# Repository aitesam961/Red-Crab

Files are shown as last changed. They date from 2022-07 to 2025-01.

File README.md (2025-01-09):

# Red-Crab: An Open Source, Modular PID controller.
RED-CRAB is an Open Source PID Controller designed for easy and flexible prototyping with PID controllers.
Offering vast selection of control parameters, this Project could be implemented in applications from hobbyist projects to home devices to industrial equipment where closed loop systems are required.

The idea of this project is to use a modular approach where different ad-ons could be used with the Basic PID controller board for controlling applications. Add-on Boards will be designed next added to the repository.
(OSHW Community can contribute in designing add-ons).

## Preview
<p align="center">
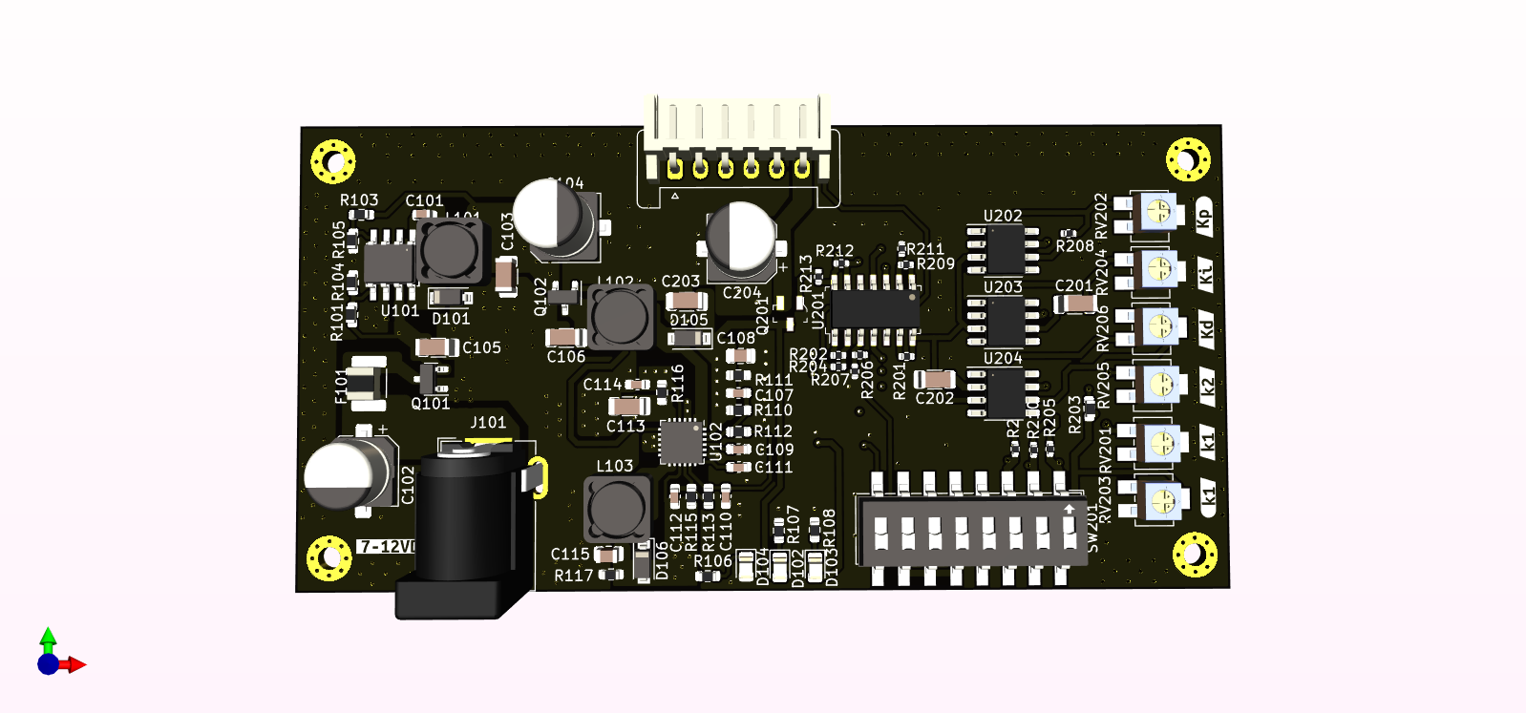
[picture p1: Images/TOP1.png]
  
</p>
<p align="right">
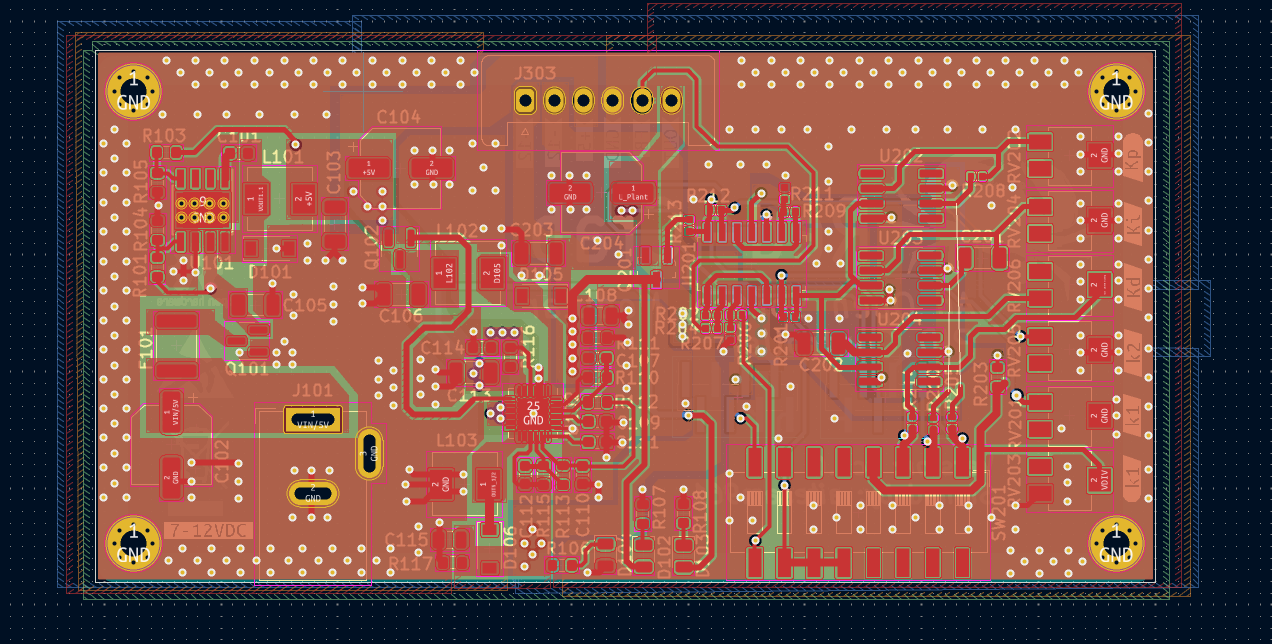
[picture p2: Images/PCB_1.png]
  
</p>
<p align="left">
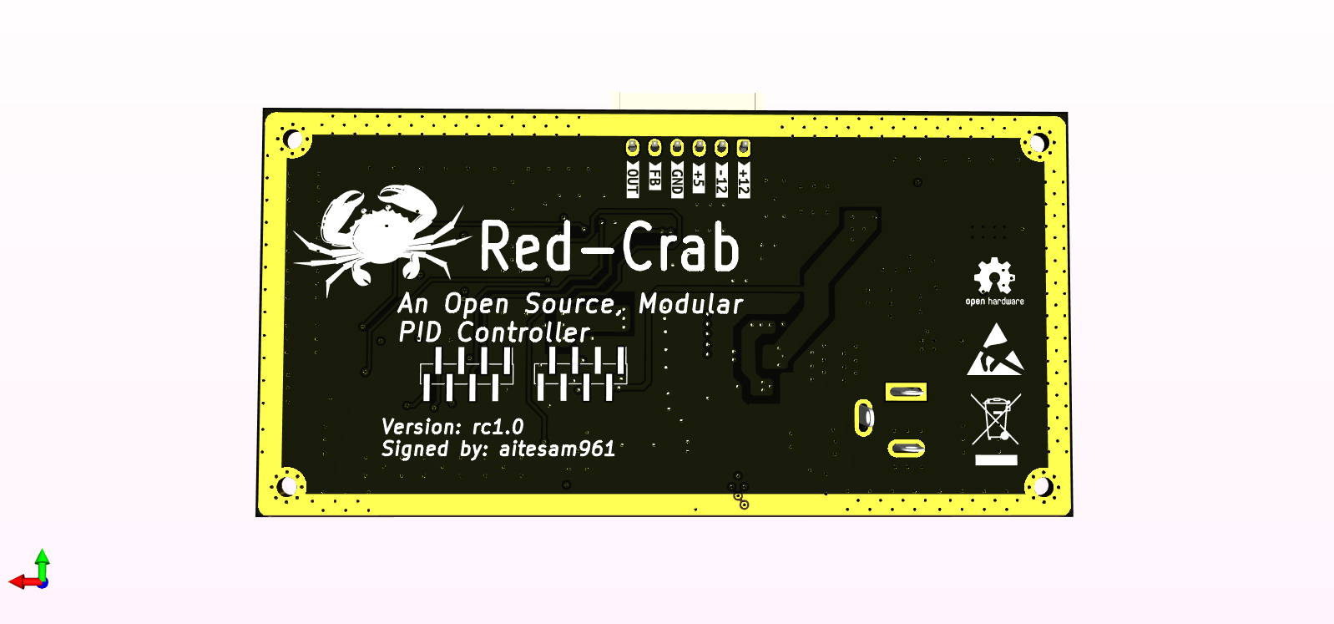
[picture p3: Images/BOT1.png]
  
</p>

## Table of contents
* [Red-Crab Overview](https://github.com/aitesam961/Red-Crab/blob/main/README.md#red-crab-overview)
* [How to Use:](https://github.com/aitesam961/Red-Crab/blob/main/README.md#how-to-use)
* [Electrical Specifications](https://github.com/aitesam961/Red-Crab/blob/main/README.md#electrical-specifications)
* [Build Your Own?](https://github.com/aitesam961/Red-Crab/blob/main/README.md#build-your-own)
* [Future Plans](https://github.com/aitesam961/Red-Crab/blob/main/README.md#future-plans)
* [Ordering Info](https://github.com/aitesam961/Red-Crab/blob/main/README.md#ordering-info)
* [Frequently Asked Questions(FAQs)](https://github.com/aitesam961/Red-Crab/blob/main/README.md#frequently-asked-questionsfaqs)
* [General Component Info](https://github.com/aitesam961/Red-Crab/blob/main/README.md#general-component-info)
* [Acknowledgements](https://github.com/aitesam961/Red-Crab/blob/main/README.md#acknowledgements)
* [License](https://github.com/aitesam961/Red-Crab/blob/main/README.md#license)

# Red-Crab Overview
### Features:
* Selectable P,PI,PID configurations.
* Adjustable GAINs using 50kOHM Potentiometers.
* DIP Switches for Controller Configuration
* Wide DC Voltage Input Range 
* 4-Layer Board with special Care to EMC/EMI for use in commercial applications.
* Open Source under GPL 3.0. (See License)
* Integrated Output Current Aplification for Larger Loads
* Ability to power External Peripherals

## How to Use:
## Electrical Specifications:

## Build Your Own?
## Future Plans
In future, this project seeks improvements and Development in following areas:
* Digital to Analog Converter Module (Ad-On Board)
* Temeprature Sensing & Amplification (Ad-On Board)
* Frequency to Voltage Converter (Ad-On Board)
* Integration with ARDUINO for Data Logging (Ad-On Board)
* Servo Actuation Control (Ad-On Board)
* Disturbance Integration Using Arduino (Ad-On Board)
## Ordering Info
You Can manufacture the PCBs from PCBWay.
[Check Out PCBWay](https://www.pcbway.com/setinvite.aspx?inviteid=440401)

Note: I am not affiliated with PCBWay. However, I just like their service and build quality.

## Frequently Asked Questions(FAQs)
## General Component Info

## Roadmap

* [x] Concept Proof
* [x] Research & Information
* [x] Finalizing The Idea
* [x] Schematics
* [x] PCB Design
* [ ] Validation & Testing
* [x] Documentation
* [ ] Future Improvements

### Contributions

Contributions are what make the open source community such an amazing place to learn, inspire, and create. Any contributions you make are **greatly appreciated**.

If you have a suggestion that would make this better, please fork the repo and create a pull request. You can also simply open an issue with the tag "enhancement".
Don't forget to give the project a star! Thanks again!

1. Fork the Project
2. Create your Feature Branch (`git checkout -b feature/AmazingFeature`)
3. Commit your Changes (`git commit -m 'Add some AmazingFeature'`)
4. Push to the Branch (`git push origin feature/AmazingFeature`)
5. Open a Pull Request

## Acknowledgements
This project is created to serve the Open Hardware Community in terms of Analog Controller Design using discrete components. Unfortunately, there isn't much of open source projects in terms of Flexible and Modular PID controller Design area.
Thye crater hopes it helps someone

## File Tree
```
.
├── Documents
│   ├── ibom.html
│   └── PID_Controller_Design.pdf
├── Images
│   ├── BOT1.png
│   ├── BOT1_RT.png
│   ├── PCB_1.png
│   ├── SID1_RT.png
│   ├── TOP1.png
│   ├── TOP1_RT.png
│   ├── TOP2_RT.png
│   ├── TOP3_RT.png
│   └── TOP4_RT.png
├── LICENSE.txt
├── Manufacturing Files
│   ├── bom.csv
│   ├── designators.csv
│   ├── gerber.zip
│   ├── netlist.ipc
│   └── positions.csv
├── MCAD Files
│   ├── Red-Crab.step
│   └── Red-Crab.wrl
├── README.md
├── Readme.txt.txt
├── References
│   ├── BananaSchplit-master
│   │   └── BananaSchplit-master
│   │       ├── assembly
│   │       │   ├── BananaSchplit-BOM.csv
│   │       │   └── BananaSchplit-Footprint-Positions.csv
│   │       ├── BananaSchplit-cache.lib
│   │       ├── BananaSchplit.kicad_pcb
│   │       ├── BananaSchplit.kicad_pcb-bak
│   │       ├── BananaSchplit.net
│   │       ├── BananaSchplit.pro
│   │       ├── BananaSchplit-rescue.dcm
│   │       ├── BananaSchplit-rescue.lib
│   │       ├── BananaSchplit.sch
│   │       ├── BananaSchplit.sch-bak
│   │       ├── BananaSchplit.xml
│   │       ├── fp-info-cache
│   │       ├── fp-lib-table
│   │       ├── gerber
│   │       │   ├── BananaSchplit-B_Cu.gbr
│   │       │   ├── BananaSchplit-B_Mask.gbr
│   │       │   ├── BananaSchplit-B_Paste.gbr
│   │       │   ├── BananaSchplit-B_SilkS.gbr
│   │       │   ├── BananaSchplit.drl
│   │       │   ├── BananaSchplit-Edge_Cuts.gbr
│   │       │   ├── BananaSchplit-F_Cu.gbr
│   │       │   ├── BananaSchplit-F_Mask.gbr
│   │       │   ├── BananaSchplit-F_Paste.gbr
│   │       │   ├── BananaSchplit-F_SilkS.gbr
│   │       │   └── BananaSchplit-Gerber.zip
│   │       ├── lib
│   │       │   ├── BananSchplitSilk.pretty
│   │       │   │   ├── BananaSchplitDrawn.png
│   │       │   │   ├── BananaSchplit.png
│   │       │   │   ├── BananaSchplitSilkLogoDrawn.kicad_mod
│   │       │   │   └── BananaSchplitSilkLogo.kicad_mod
│   │       │   ├── TPS65131RGET.lib
│   │       │   ├── TPS65131RGET.mod
│   │       │   └── TPS65131RGET.stp
│   │       ├── LICENSE
│   │       ├── README.md
│   │       └── sym-lib-table
│   ├── Screenshot 2022-07-08 204516.png
│   └── The_Design_of_the_PID_Controller.pdf
└── Source Files
    └── Red_Crab_KiCAD_Source
        ├── fp-info-cache
        ├── Passives.kicad_sch
        ├── PID_Core.kicad_sch
        ├── place_footprints.log
        ├── Power.kicad_sch
        ├── Red-Crab.kicad_pcb
        ├── Red-Crab.kicad_prl
        ├── Red-Crab.kicad_pro
        ├── Red-Crab.kicad_sch
        └── shapes3D
            ├── C_0603_1608Metric.wrl
            ├── C_0805_2012Metric.wrl
            ├── C_1206_3216Metric.wrl
            ├── CP_Elec_6.3x5.3.wrl
            ├── CP_Elec_6.3x7.7.wrl
            ├── DC-jack.wrl
            ├── D_SOD-123.wrl
            ├── Fuse_1210_3225Metric.wrl
            ├── HSOP-8-1EP_3.9x4.9mm_P1.27mm_EP2.41x3.1mm.wrl
            ├── HTSOP-8-1EP_3.9x4.9mm_Pitch1.27mm.wrl
            ├── JST_EH_S6B-EH_1x06_P2.50mm_Horizontal.wrl
            ├── L_Bourns_SRR1260.wrl
            ├── LED_0805_2012Metric.wrl
            ├── POT_SMD.wrl
            ├── QFN-24-1EP_4x4mm_P0.5mm_EP2.6x2.6mm.wrl
            ├── R_0402_1005Metric.wrl
            ├── R_0603_1608Metric.wrl
            ├── SOIC-14_3.9x8.7mm_P1.27mm.wrl
            ├── SOT-23.wrl
            └── SW_DIP_SPSTx08_Slide_6.7x21.88mm_W8.61mm_P2.54mm_LowProfile.wrl

14 directories, 87 files
```
## License
This Project is published under General Public License V3.0 See `LICENSE.txt` for more information.
> https://www.gnu.org/licenses/quick-guide-gplv3.html

<p align="right">(<a href="#top">back to top</a>)</p>

* [Jump To Start](https://github.com/maitesam/OpenADSP/blob/main/README.md#Description)

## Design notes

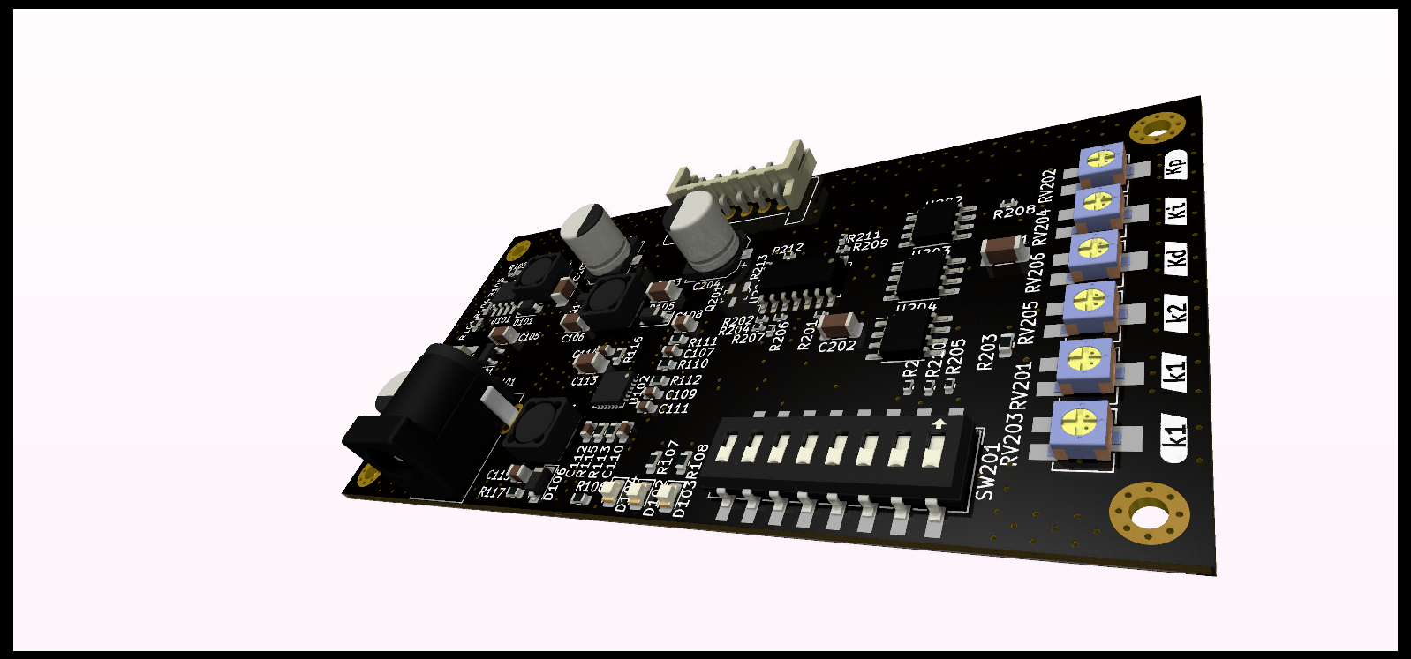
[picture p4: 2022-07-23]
Images/SID1_RT.png

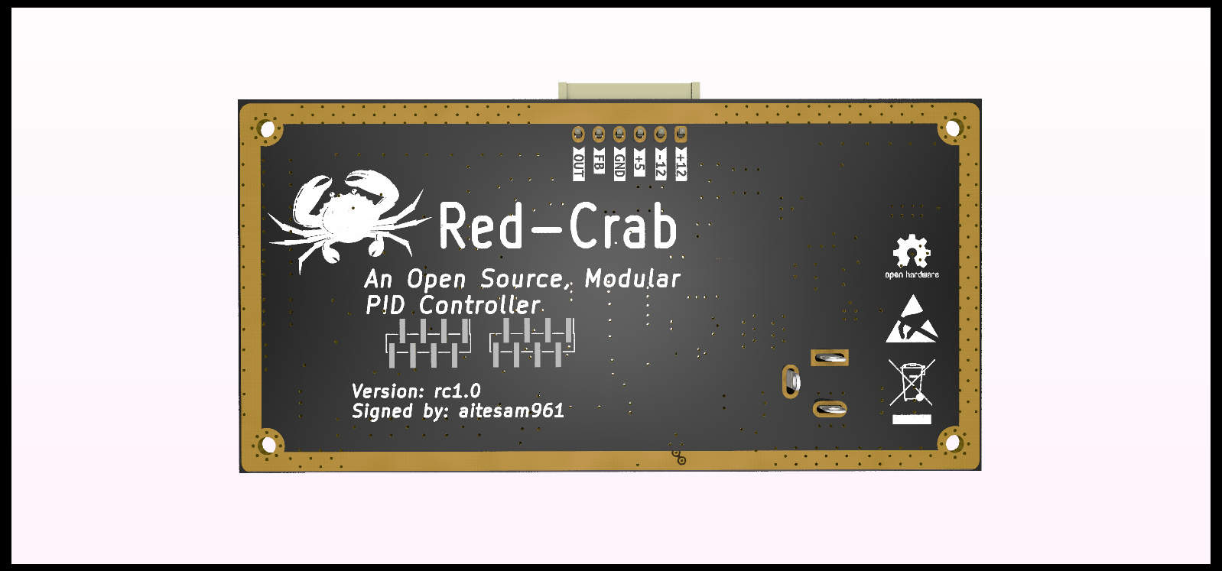
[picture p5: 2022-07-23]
Images/BOT1_RT.png

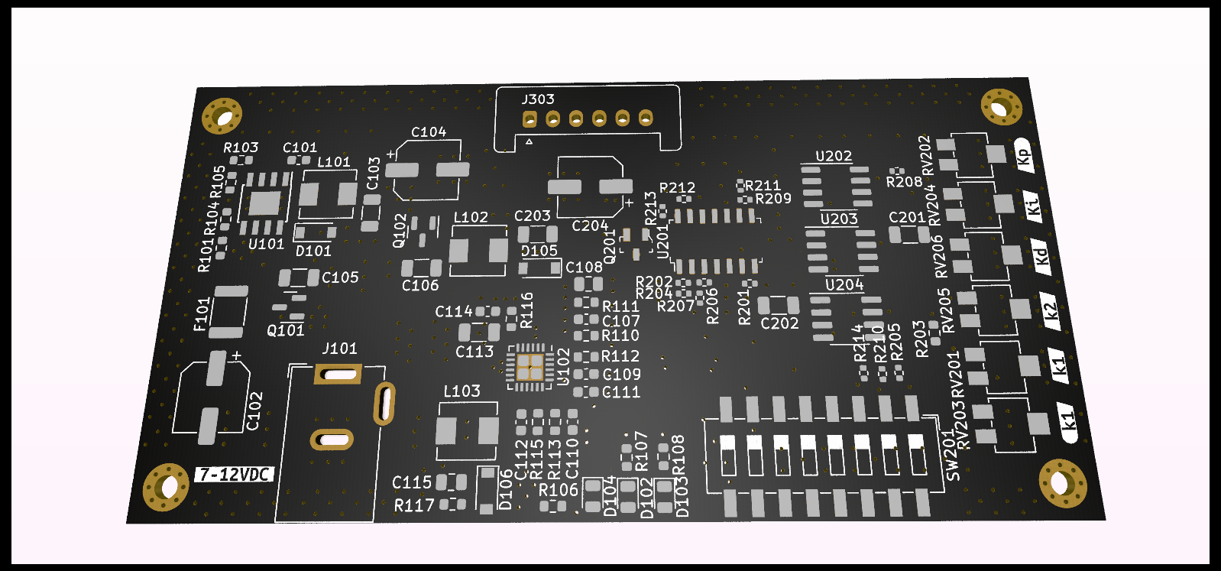
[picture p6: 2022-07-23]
Images/TOP4_RT.png

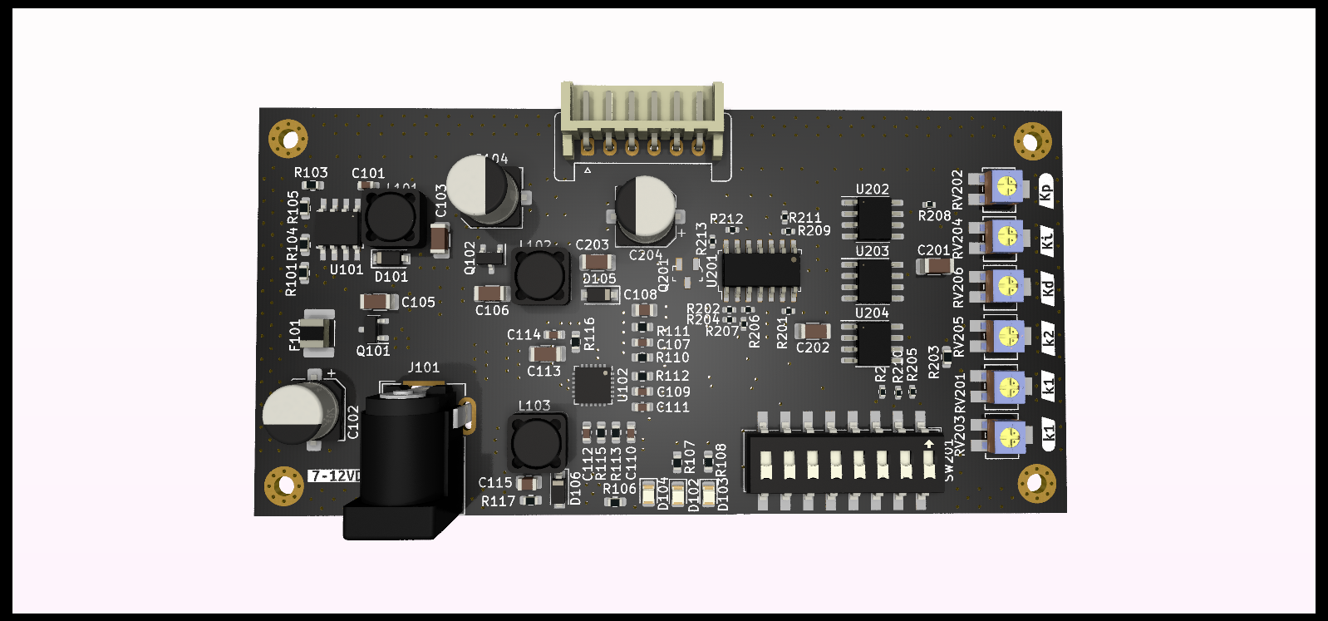
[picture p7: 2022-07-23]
Images/TOP3_RT.png

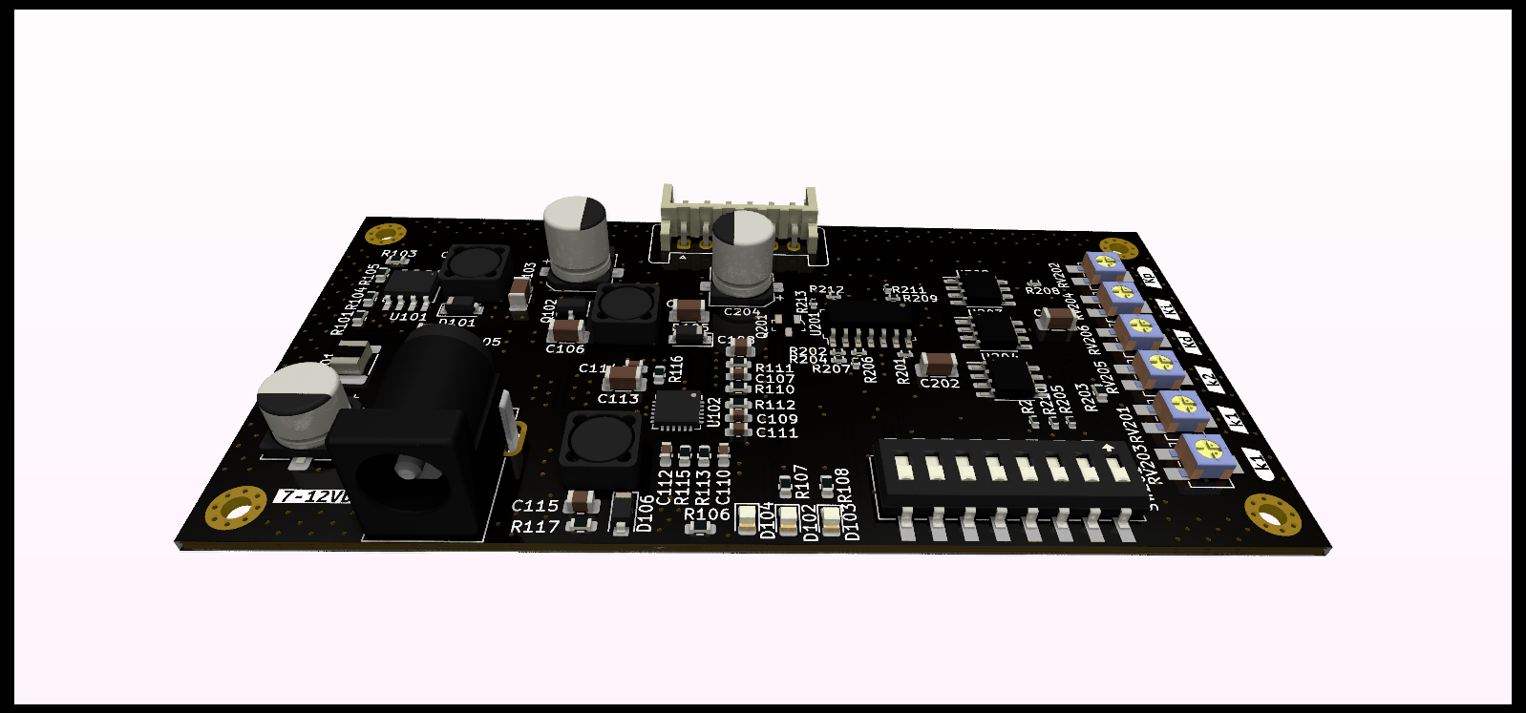
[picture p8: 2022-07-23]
Images/TOP1_RT.png

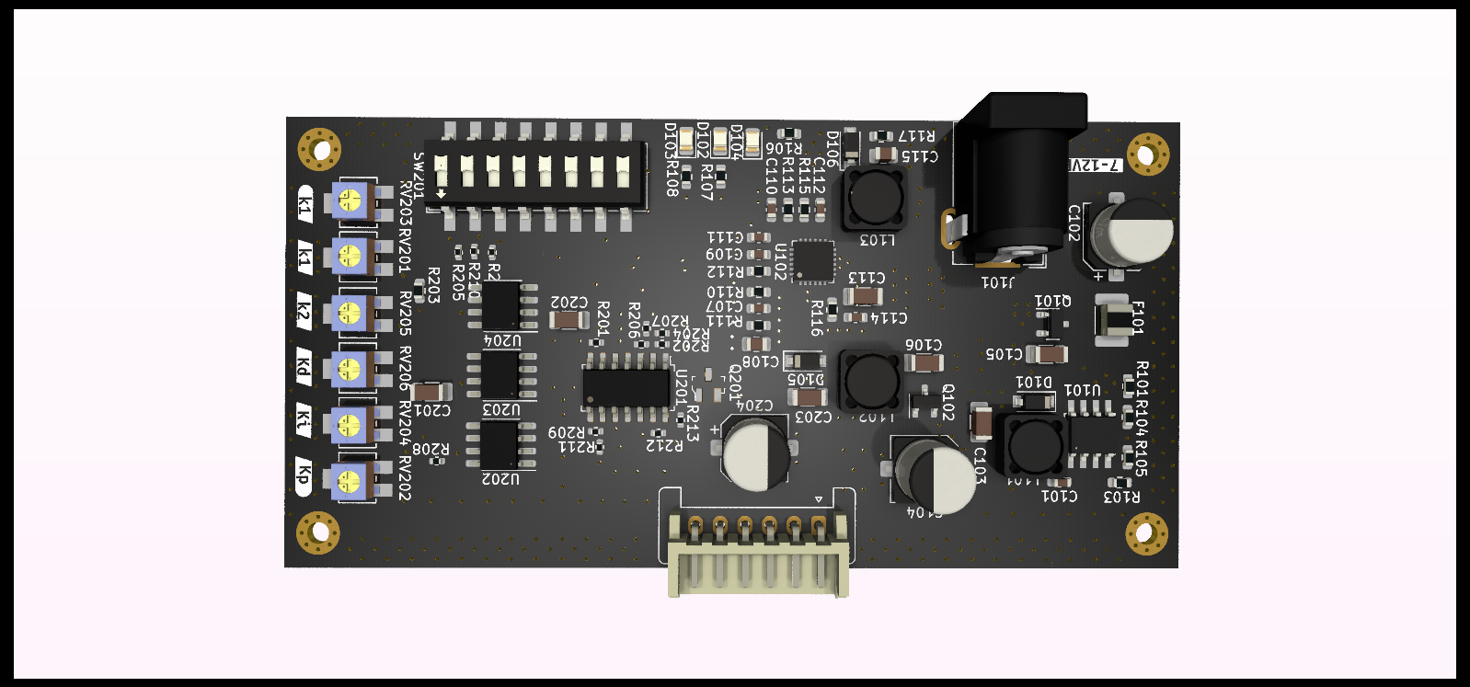
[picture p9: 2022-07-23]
Images/TOP2_RT.png

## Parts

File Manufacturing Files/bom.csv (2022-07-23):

Designator | Footprint | Quantity | Value | LCSC Part #
J303 | Stocko_MKS_1656-6-0-606_1x6_P2.50mm_Vertical | 1 | Screw_Terminal_01x06
RV204 | Potentiometer_Bourns_3214X_Vertical | 1 | 100k
RV203 | Potentiometer_Bourns_3214X_Vertical | 1 | 50k
U203 | SOP-8_3.76x4.96mm_P1.27mm | 1 | LM741
C105 | C_1206_3216Metric | 1 | 10u | C13585
R117 | R_0603_1608Metric | 1 | 12k | C22790
U204 | SOP-8_3.76x4.96mm_P1.27mm | 1 | LM741
Q101 | SOT-23 | 1 | AO3401A | C15127
C103 | C_1206_3216Metric | 1 | 10u | C13585
C113 | C_1206_3216Metric | 1 | 10u | C13585
R205 | R_0402_1005Metric | 1 | 1k
H302 | MountingHole_2.2mm_M2_Pad_Via | 1 | MountingHole_Pad
RV206 | Potentiometer_Bourns_3214X_Vertical | 1 | 100k
C101 | C_0603_1608Metric | 1 | 10n | C57112
R213 | R_0402_1005Metric | 1 | 100
R106 | R_0603_1608Metric | 1 | 5k1 | C23186
R202 | R_0402_1005Metric | 1 | 1k
D104 | LED_0805_2012Metric | 1 | YELLOW | C2296
R111 | R_0603_1608Metric | 1 | 12k | C22790
C109 | C_0603_1608Metric | 1 | 10n | C57112
R107 | R_0603_1608Metric | 1 | 4k3 | C23159
D105 | D_SOD-123 | 1 | B5819W | C8598
R212 | R_0402_1005Metric | 1 | 1k
U202 | SOP-8_3.76x4.96mm_P1.27mm | 1 | LM741
D101 | D_SOD-123 | 1 | B5819W | C8598
C102 | CP_Elec_6.3x5.3 | 1 | 22uF/25V
RV202 | Potentiometer_Bourns_3214X_Vertical | 1 | 50k
R203 | R_0603_1608Metric | 1 | 10k | C22775
H301 | MountingHole_2.2mm_M2_Pad_Via | 1 | MountingHole_Pad
C204 | CP_Elec_6.3x7.7 | 1 | 220u | C127327
J101 | BarrelJack_GCT_DCJ200-10-A_Horizontal | 1 | Barrel_Jack_Switch
R104 | R_0603_1608Metric | 1 | 100k | C25803
C104 | CP_Elec_6.3x7.7 | 1 | 220u | C127327
R207 | R_0402_1005Metric | 1 | 1k
H304 | MountingHole_2.2mm_M2_Pad_Via | 1 | MountingHole_Pad
Q201 | SOT-23-3 | 1 | FDV301N | FDV301N
Q102 | SOT-23 | 1 | AO3401A | C15127
R204 | R_0402_1005Metric | 1 | 1k
C201 | C_1206_3216Metric | 1 | 1u | C13585
C202 | C_1206_3216Metric | 1 | 1u | C13585
R105 | R_0603_1608Metric | 1 | 3k3 | C22978
R201 | R_0402_1005Metric | 1 | 1k
L101 | L_Sunlord_MWSA0518_5.4x5.2mm | 1 | 47u | C169398
R116 | R_0603_1608Metric | 1 | 100 | C22775
U101 | TI_SO-PowerPAD-8_ThermalVias | 1 | TPS5430DDA | C9864
C106 | C_1206_3216Metric | 1 | 10u | C13585
R113 | R_0603_1608Metric | 1 | 100k | C25803
R210 | R_0402_1005Metric | 1 | 1k
R110 | R_0603_1608Metric | 1 | 1M | C22935
R206 | R_0402_1005Metric | 1 | 1k
R103 | R_0603_1608Metric | 1 | 10k | C25804
C110 | C_0603_1608Metric | 1 | 220n | C21120
L103 | L_Sunlord_MWSA0518_5.4x5.2mm | 1 | 10u | C139506
R115 | R_0603_1608Metric | 1 | 1M | C22935
D103 | LED_0805_2012Metric | 1 | RED | C84256
R112 | R_0603_1608Metric | 1 | 110k | C25805
C107 | C_0603_1608Metric | 1 | 6p8 | C1679
RV201 | Potentiometer_Bourns_3214X_Vertical | 1 | 50k
SW201 | SW_DIP_SPSTx08_Slide_6.7x21.88mm_W8.61mm_P2.54mm_LowProfile | 1 | SW_DIP_x06
C203 | C_1206_3216Metric | 1 | 10u | C13585
L102 | L_Sunlord_MWSA0518_5.4x5.2mm | 1 | 10u | C139506
C115 | C_0805_2012Metric | 1 | 22u | C45783
C114 | C_0603_1608Metric | 1 | 100n | C14663
H303 | MountingHole_2.2mm_M2_Pad_Via | 1 | MountingHole_Pad
C112 | C_0603_1608Metric | 1 | 8p2 | C1685
R101 | R_0603_1608Metric | 1 | 100k | C25803
R208 | R_0402_1005Metric | 1 | 1k
F101 | Fuse_1812_4532Metric | 1 | 500mA | C151168
D102 | LED_0805_2012Metric | 1 | GREEN | C2297
C111 | C_0603_1608Metric | 1 | 4n7 | C53987
D106 | D_SOD-123 | 1 | B5819W | C8598
R214 | R_0402_1005Metric | 1 | 1k
R209 | R_0402_1005Metric | 1 | 6k
C108 | C_0805_2012Metric | 1 | 22u | C45783
R211 | R_0402_1005Metric | 1 | 6k
U102 | QFN-24-1EP_4x4mm_P0.5mm_EP2.6x2.6mm | 1 | TPS65131RGER | C87663
U201 | SOIC-14_W3.9mm | 1 | LM324ADR | LM324ADR
R108 | R_0603_1608Metric | 1 | 1k5 | C22843
RV205 | Potentiometer_Bourns_3214X_Vertical | 1 | 50k
J302 | PinHeader_1x08_P1.27mm_Vertical_SMD_Pin1Left | 1 | OSTTC080162 | OSTTC080162
J301 | PinHeader_1x08_P1.27mm_Vertical_SMD_Pin1Left | 1 | OSTTC080162 | OSTTC080162

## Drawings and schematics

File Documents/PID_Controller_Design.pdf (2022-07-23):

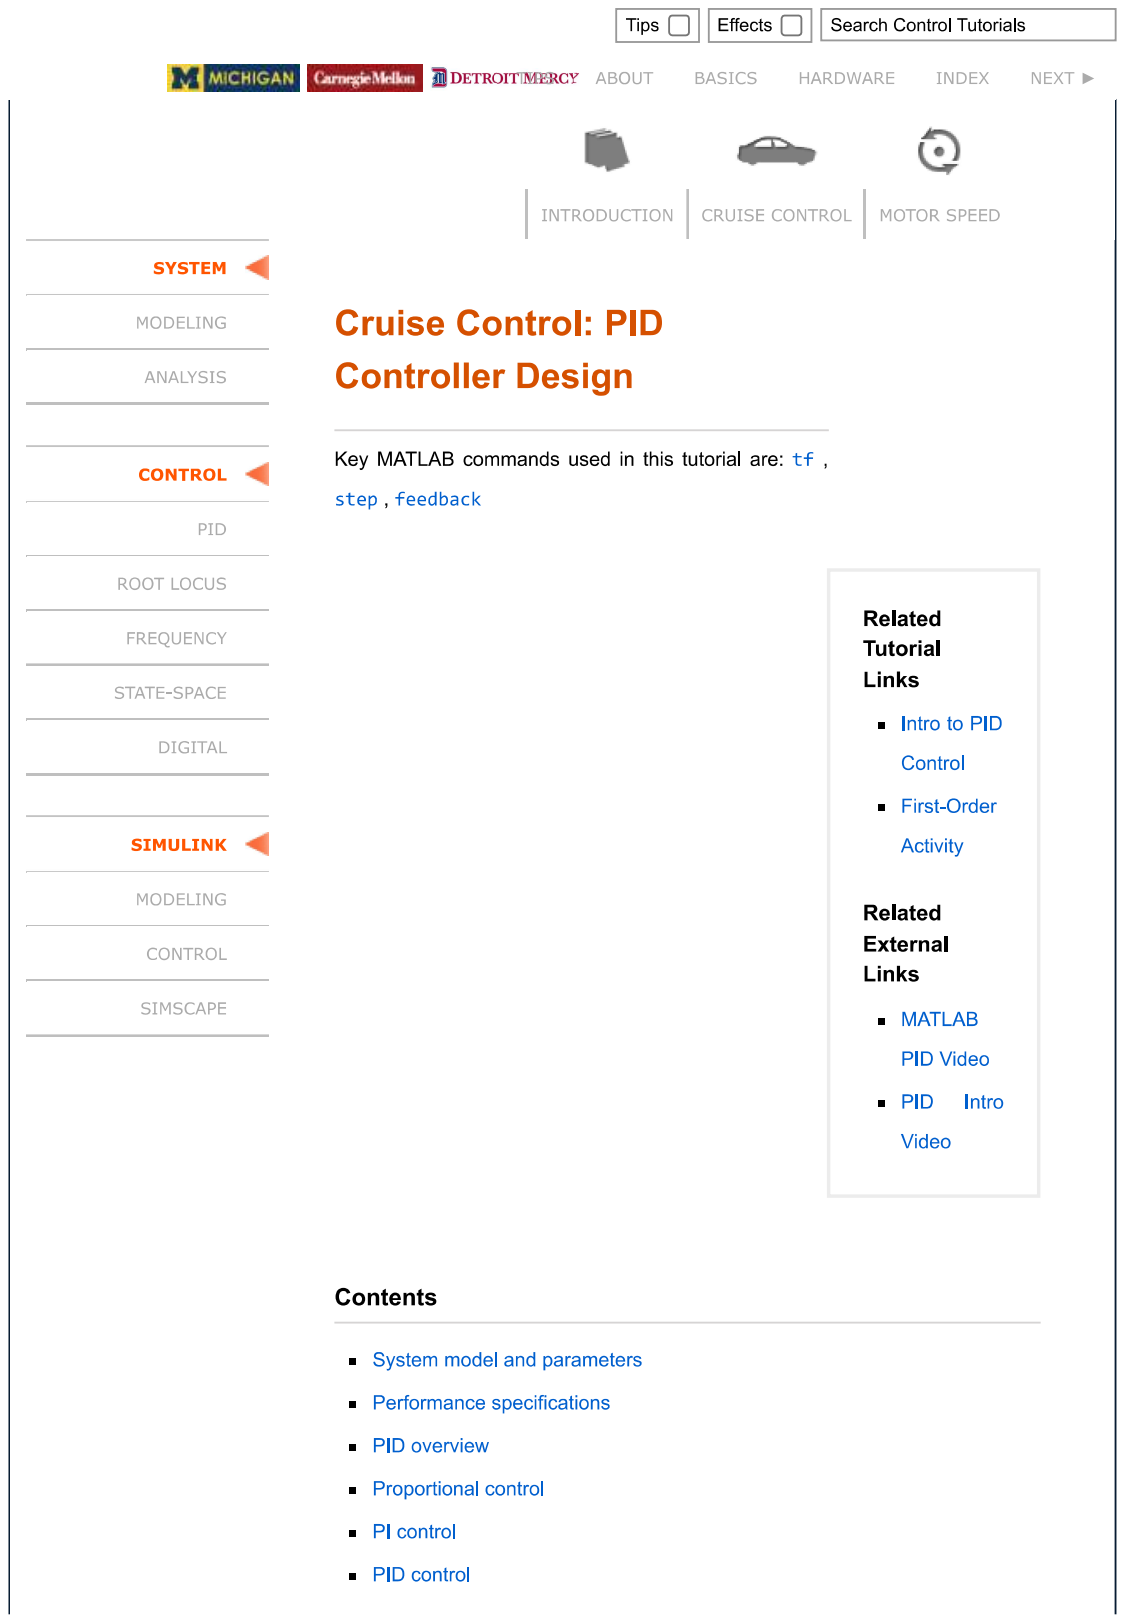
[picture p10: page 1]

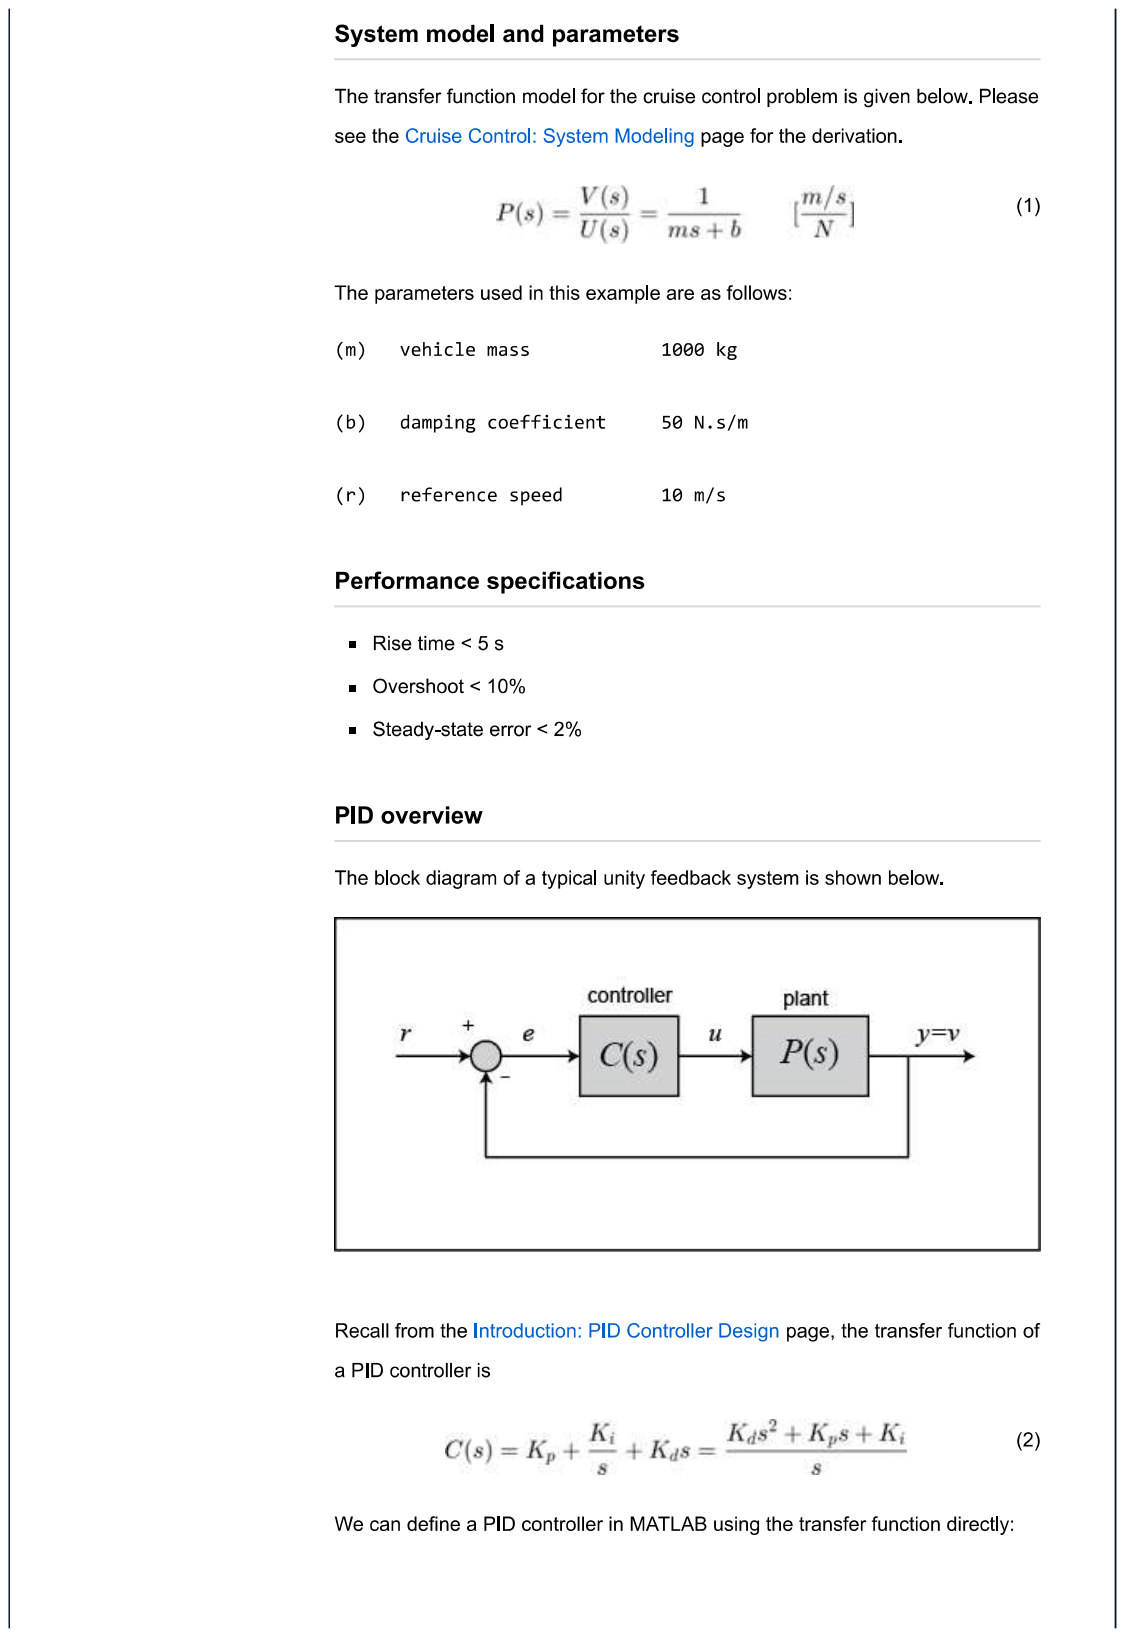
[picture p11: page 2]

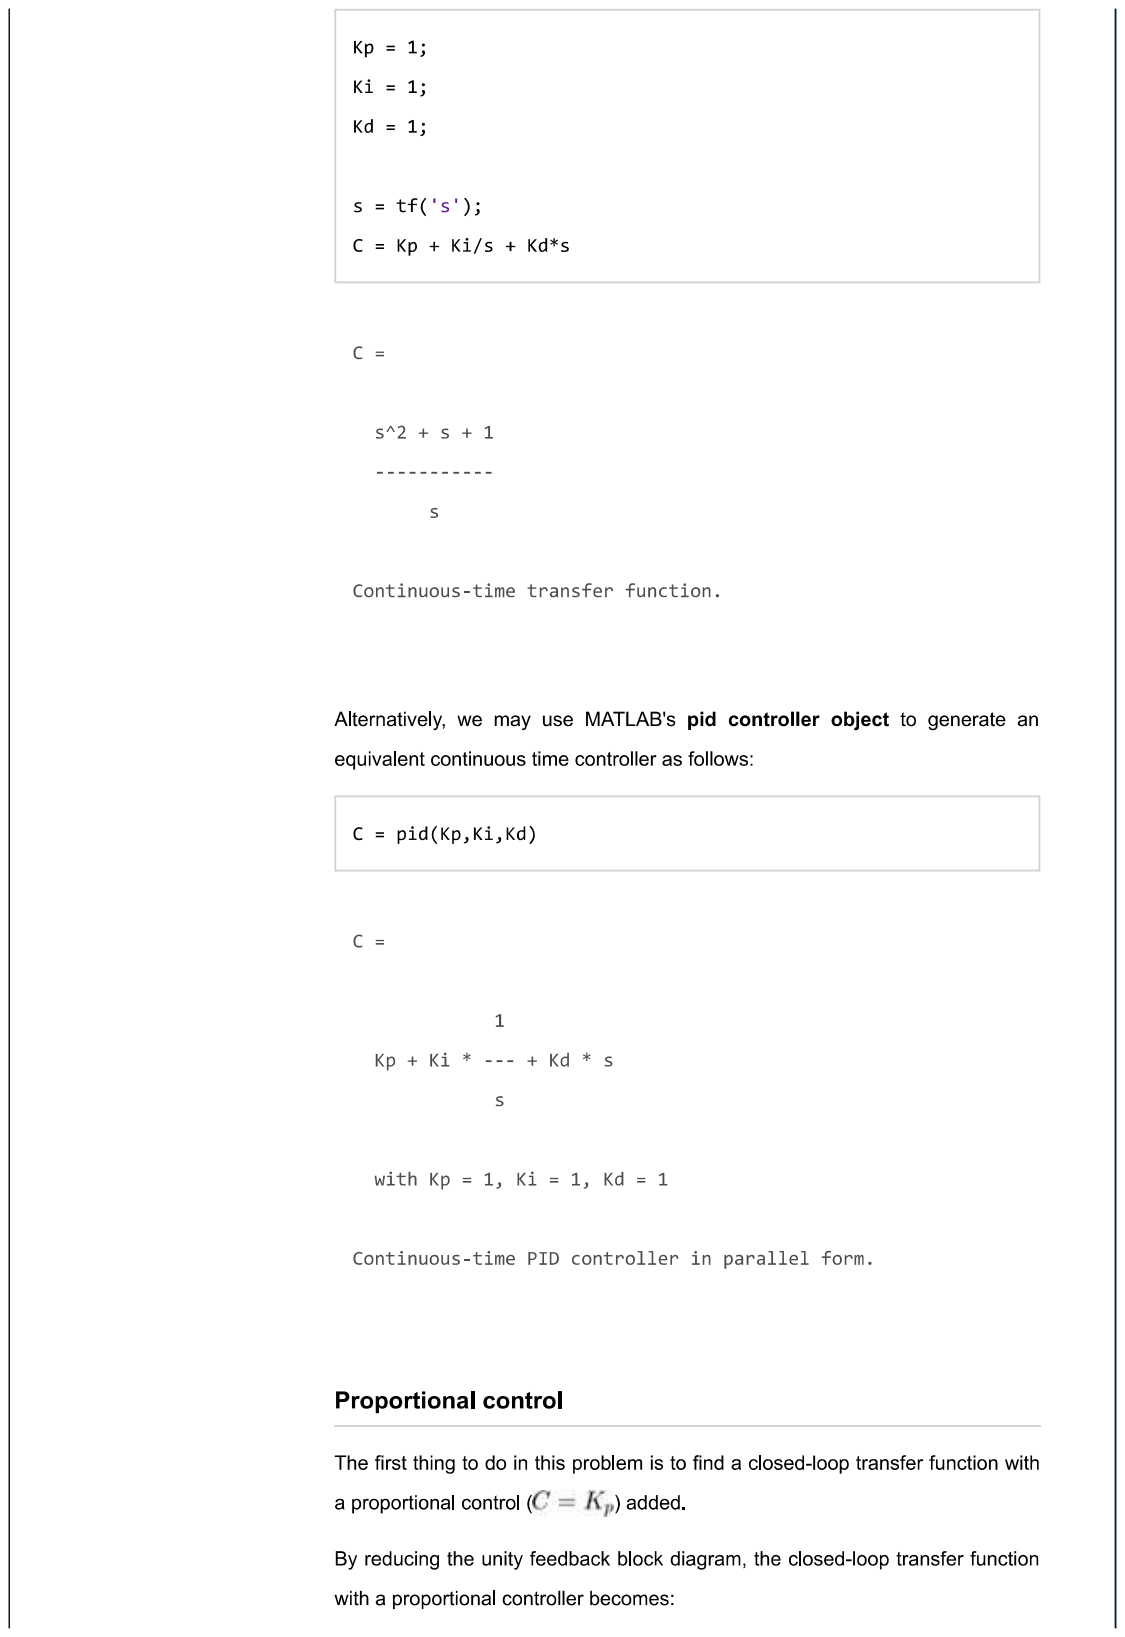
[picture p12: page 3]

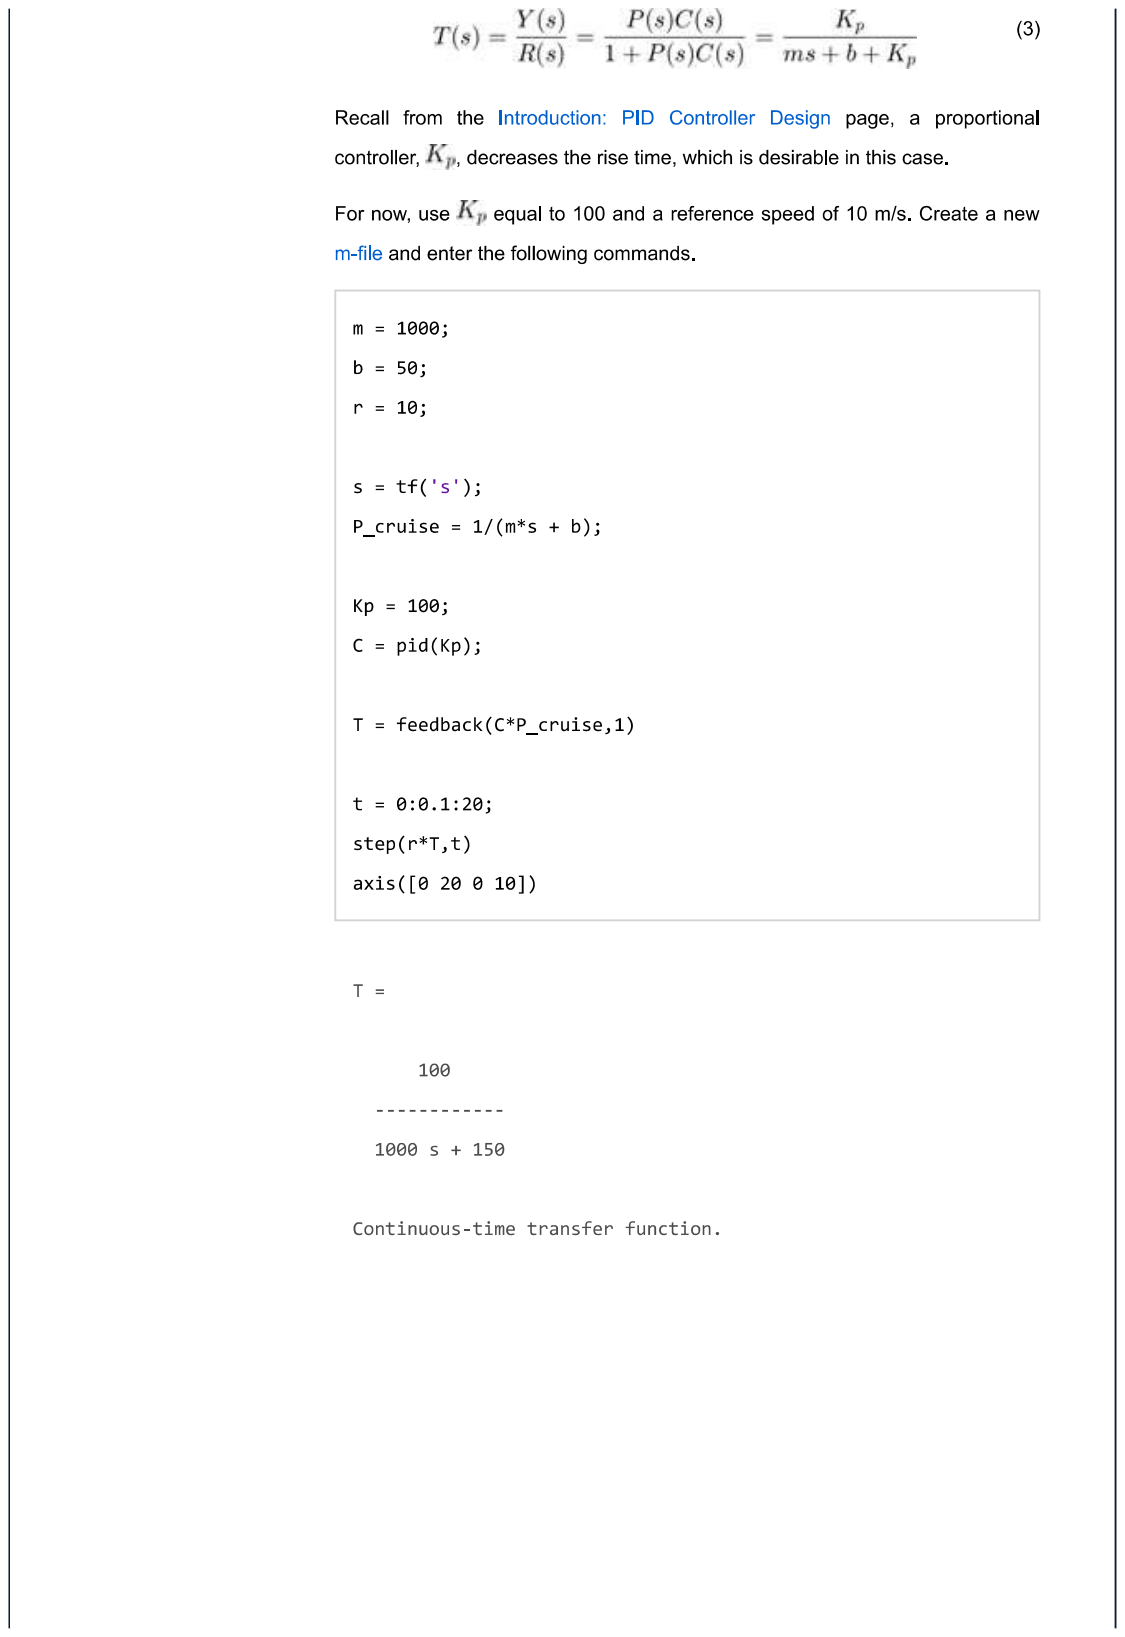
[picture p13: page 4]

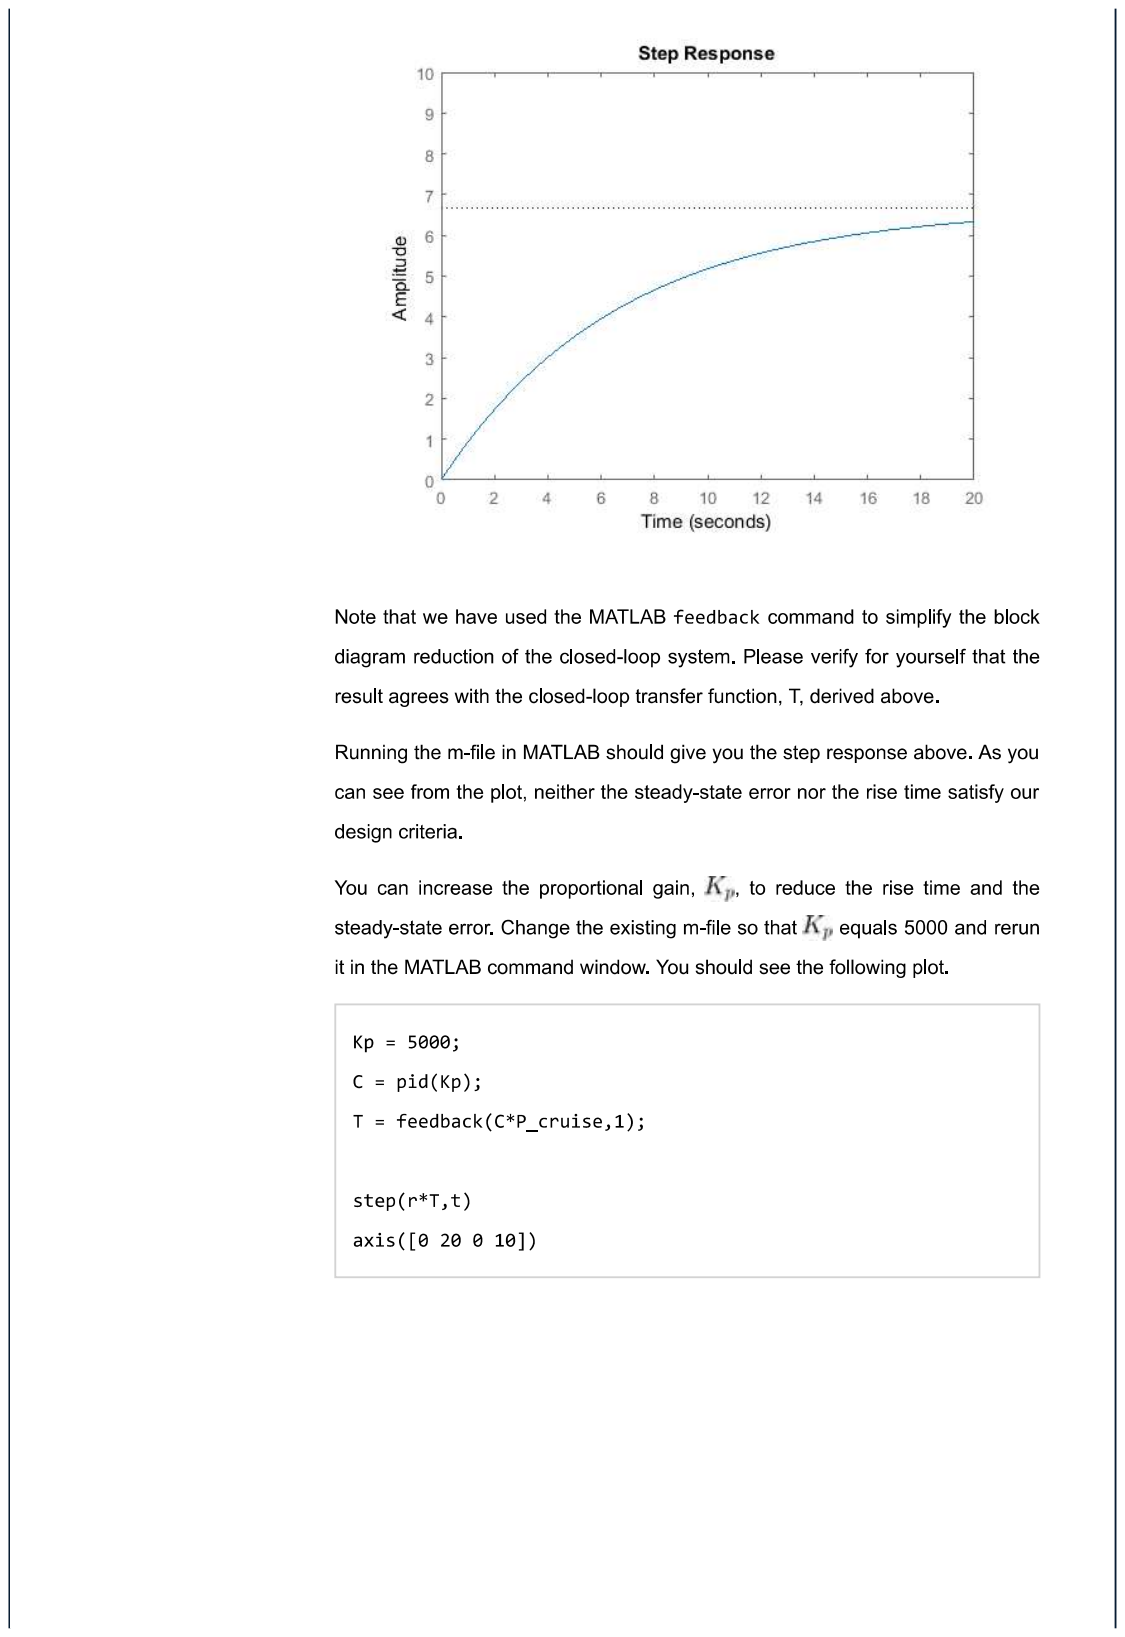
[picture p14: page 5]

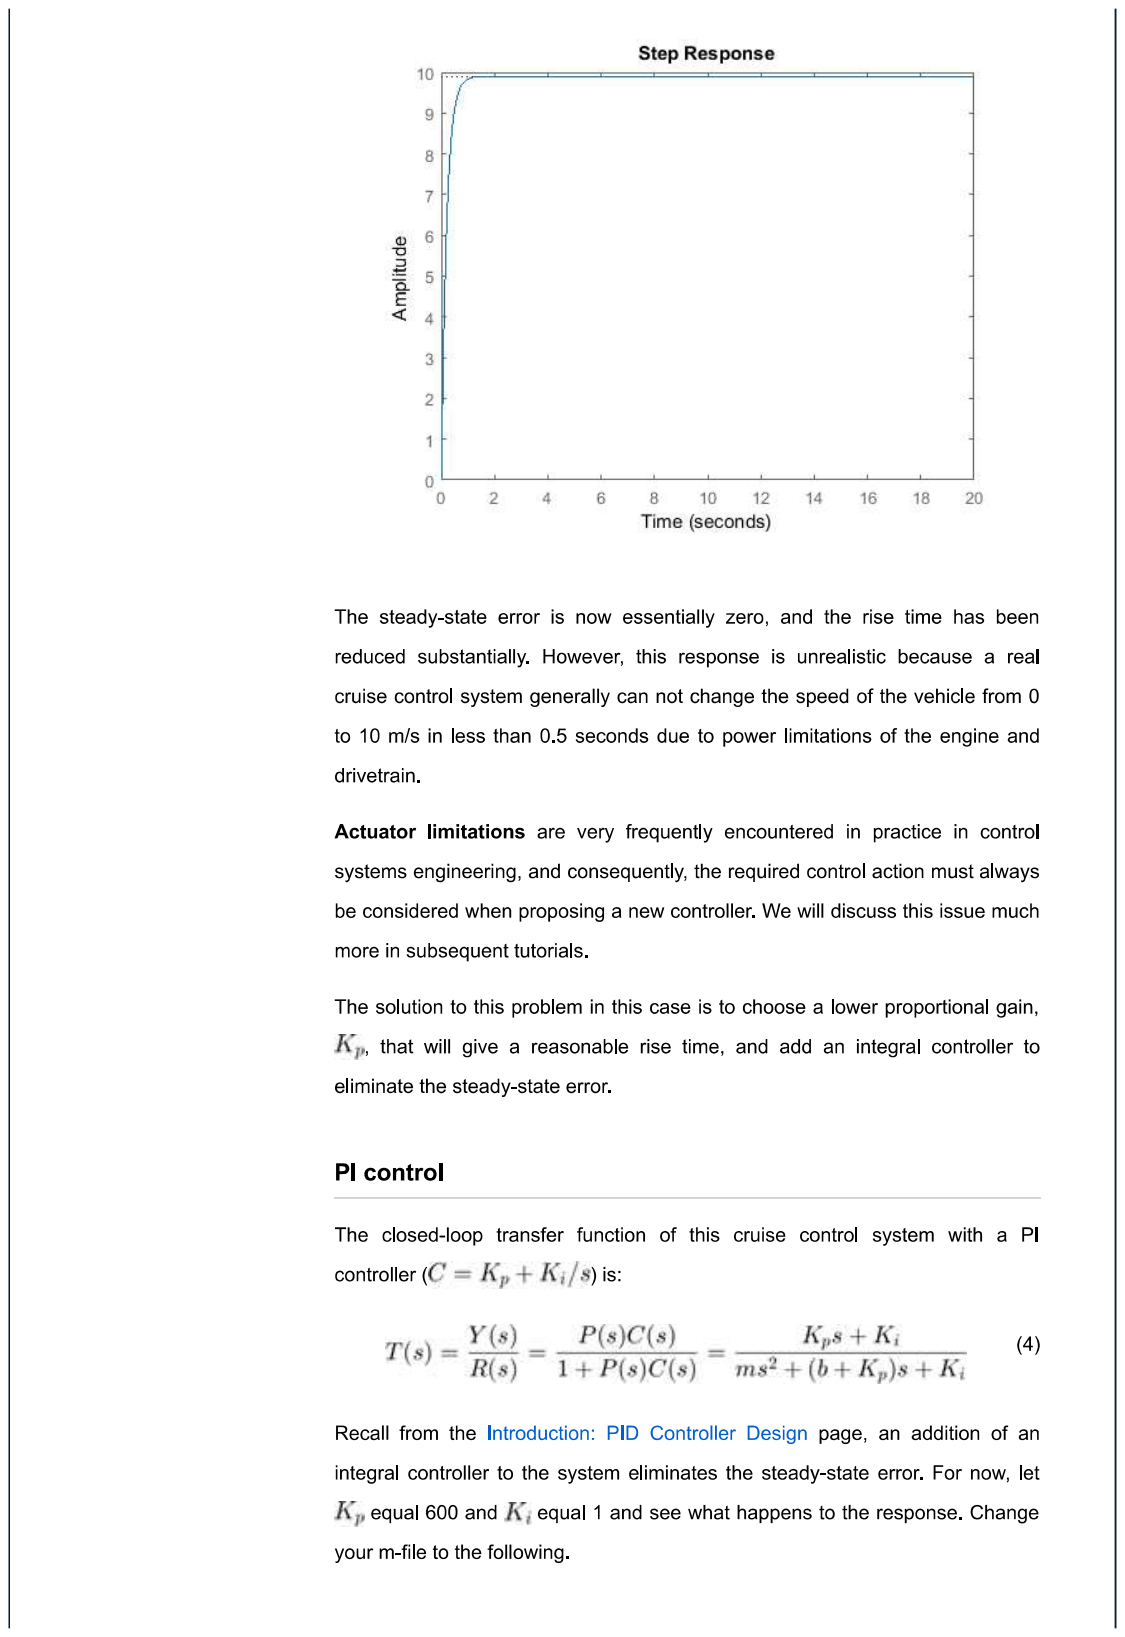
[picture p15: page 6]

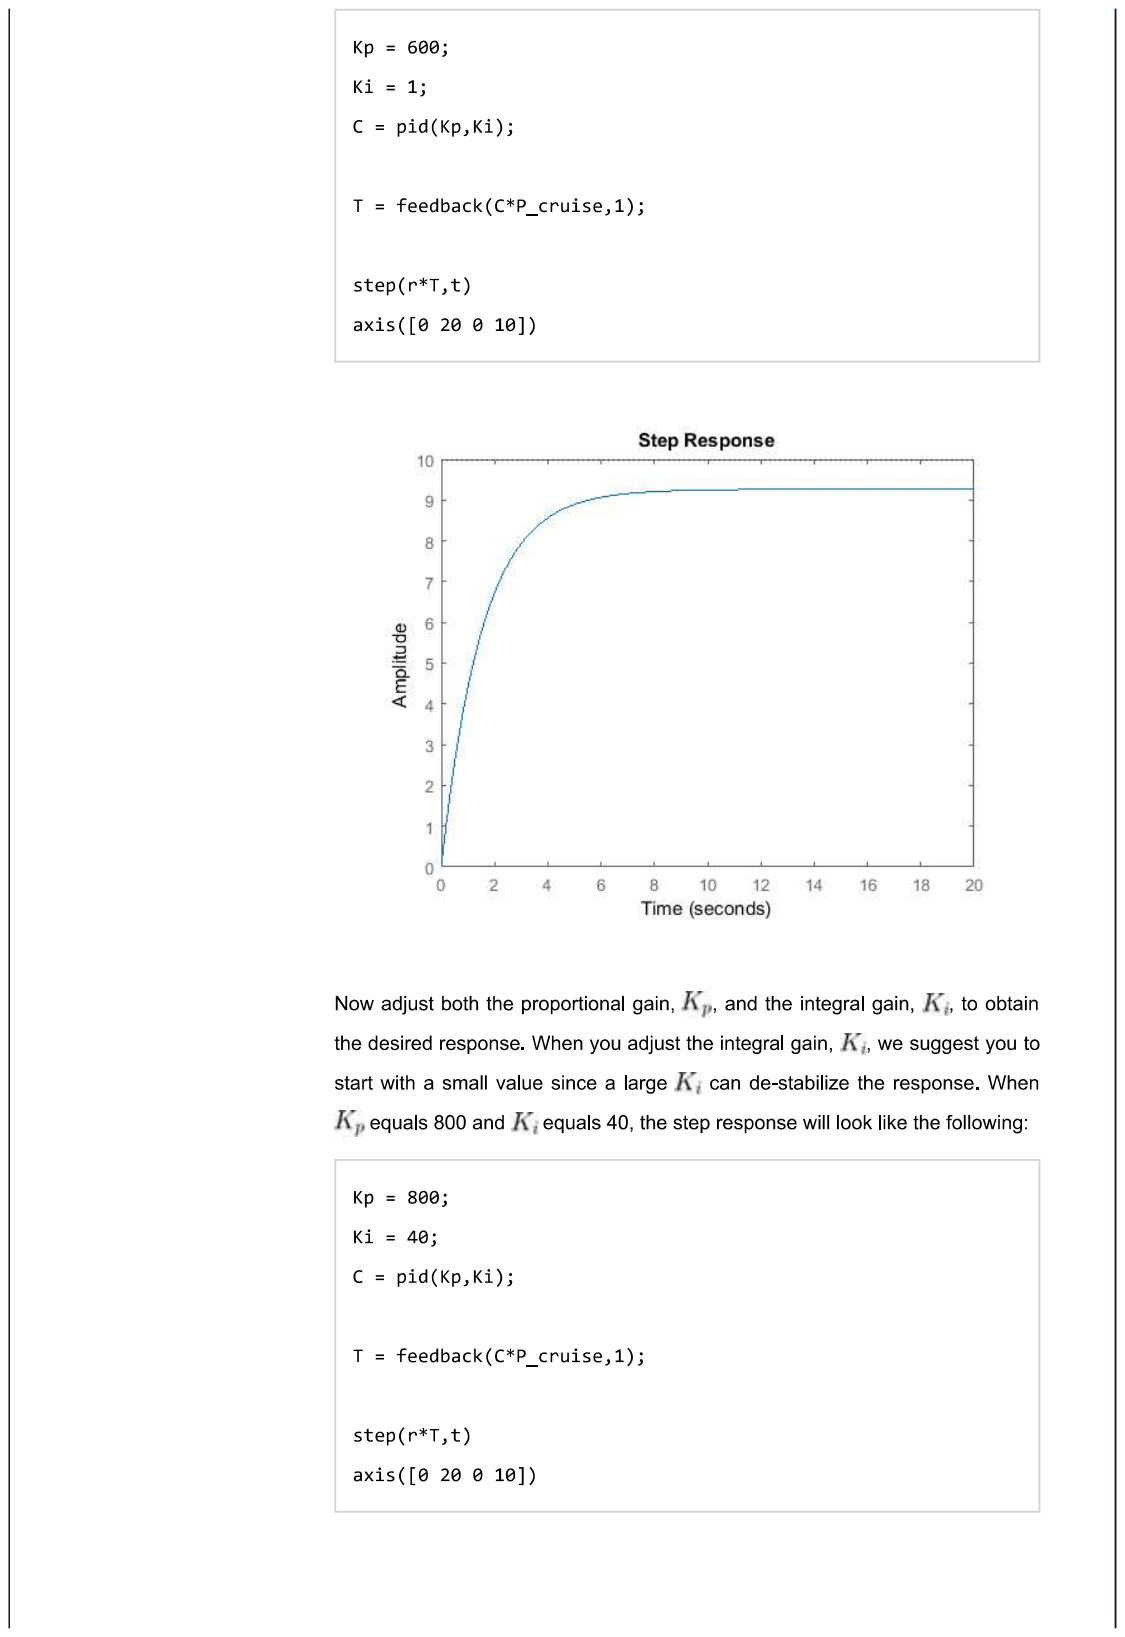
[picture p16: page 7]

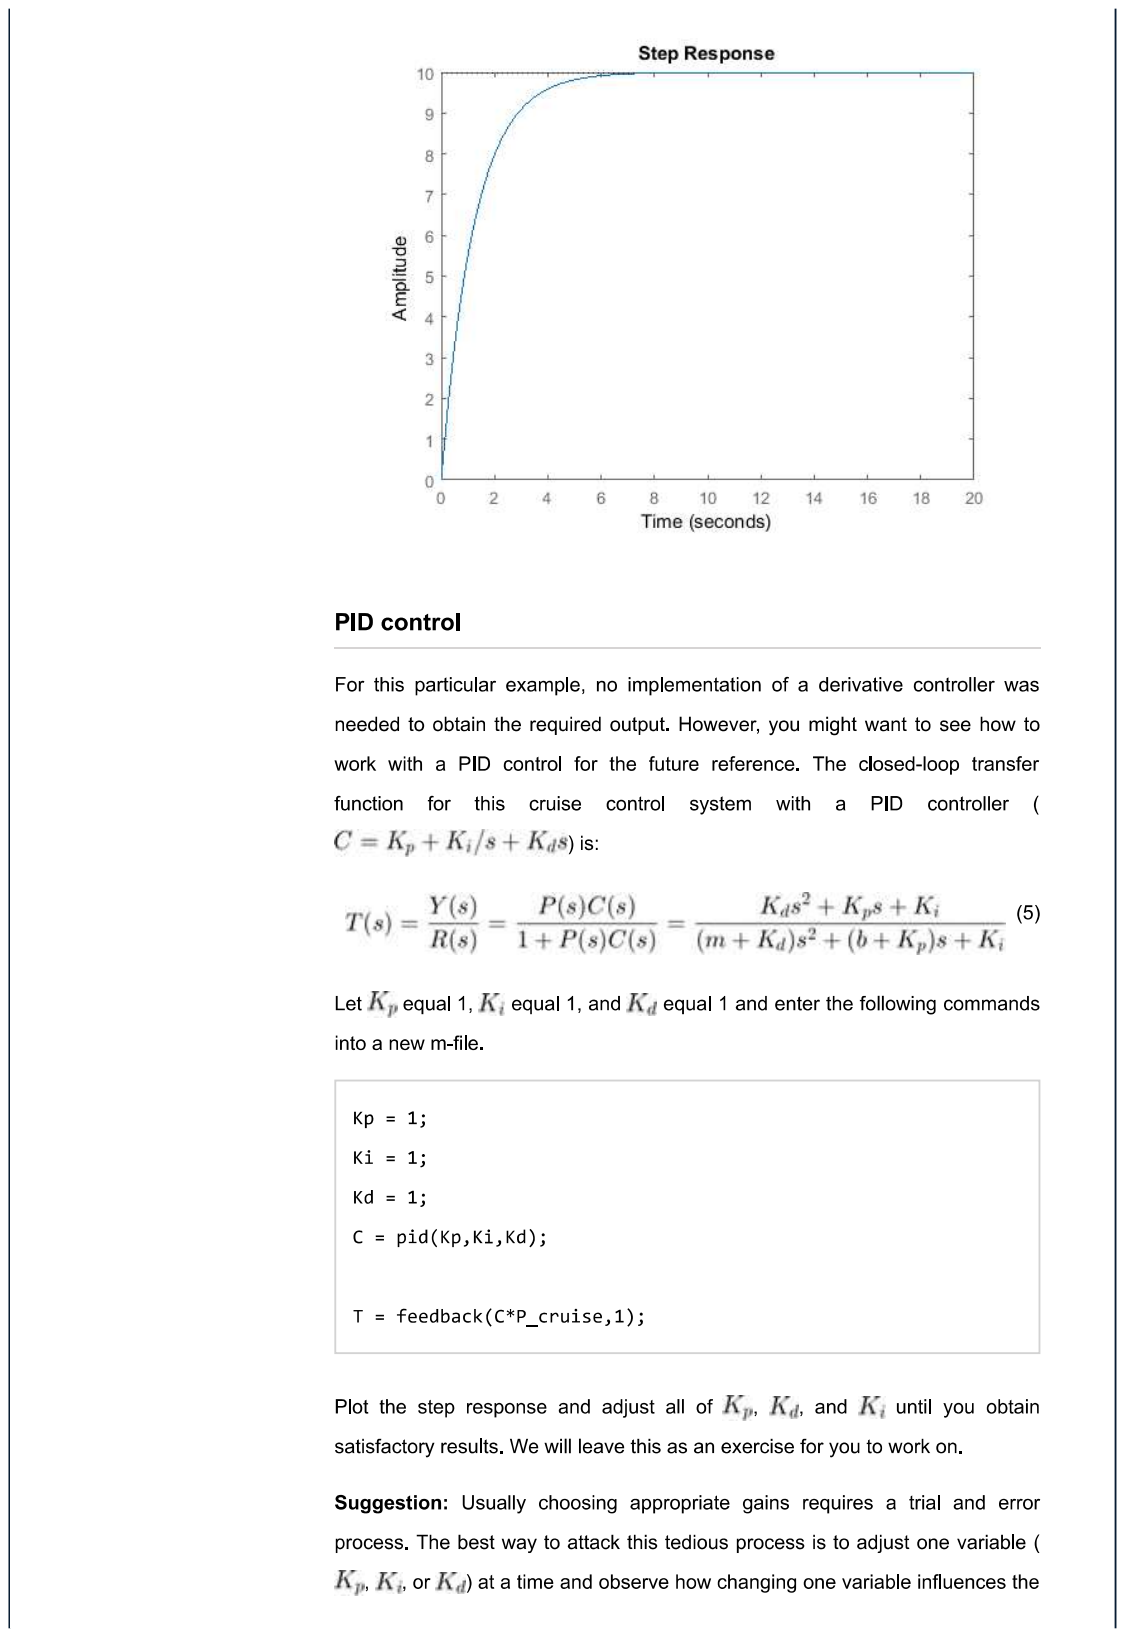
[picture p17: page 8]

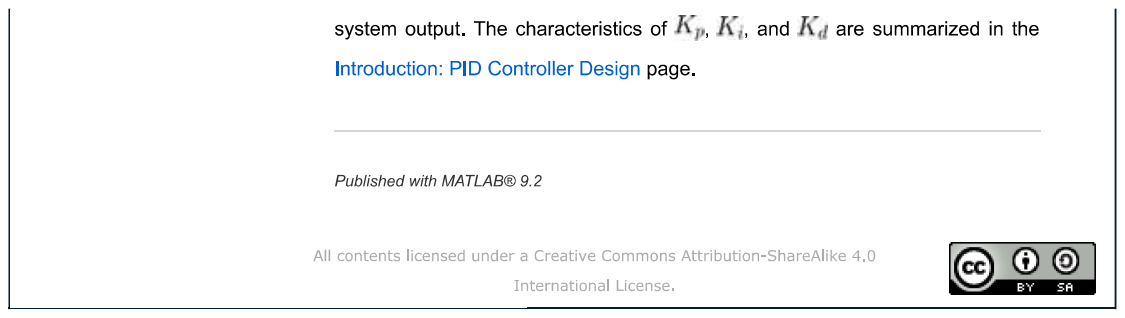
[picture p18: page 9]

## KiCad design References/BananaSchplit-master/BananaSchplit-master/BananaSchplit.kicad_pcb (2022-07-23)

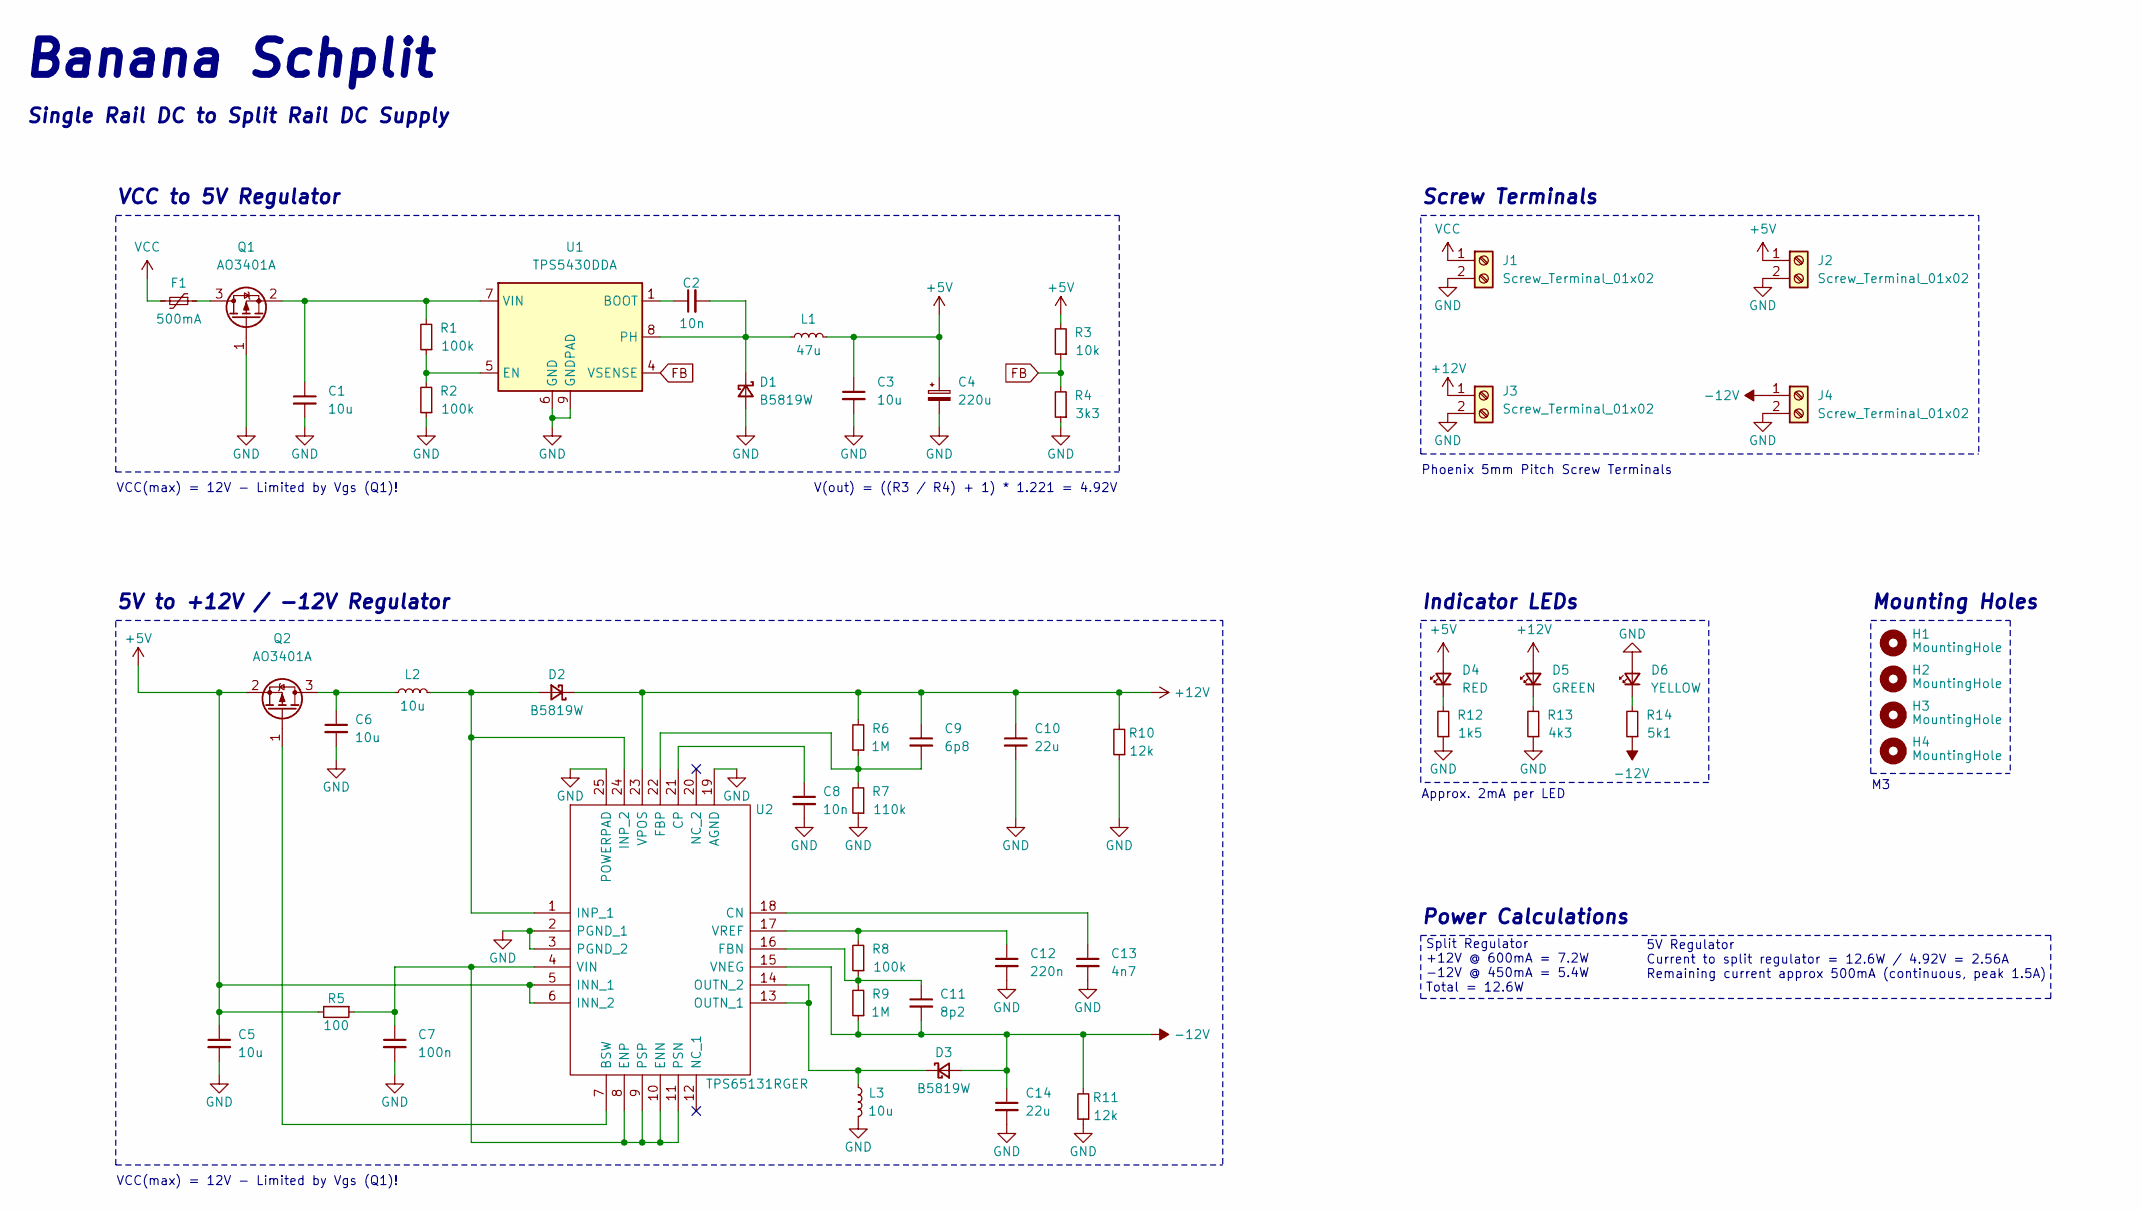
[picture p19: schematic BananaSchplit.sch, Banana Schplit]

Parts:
C1, C3, C5, C6: 10u; C_1206_3216Metric; LCSC Part # C13585
C2, C8: 10n; C_0603_1608Metric; LCSC Part # C57112
C4: 220u; CP_Elec_6.3x7.7; LCSC Part # C127327
C7: 100n; C_0603_1608Metric; LCSC Part # C14663
C9: 6p8; C_0603_1608Metric; LCSC Part # C1679
C10, C14: 22u; C_0805_2012Metric; LCSC Part # C45783
C11: 8p2; C_0603_1608Metric; LCSC Part # C1685
C12: 220n; C_0603_1608Metric; LCSC Part # C21120
C13: 4n7; C_0603_1608Metric; LCSC Part # C53987
D1, D2, D3: B5819W; D_SOD-123; LCSC Part # C8598
D4: RED; LED_0805_2012Metric; LCSC Part # C84256
D5: GREEN; LED_0805_2012Metric; LCSC Part # C2297
D6: YELLOW; LED_0805_2012Metric; LCSC Part # C2296
F1: 500mA; Fuse_1812_4532Metric; LCSC Part # C151168
H1, H2, H3, H4: MountingHole; MountingHole_3.2mm_M3
J1, J2, J3, J4: Screw_Terminal_01x02; TerminalBlock_Phoenix_PT-1,5-2-5.0-H_1x02_P5.00mm_Horizontal
L1: 47u; SWRB1204S; LCSC Part # C169398
L2, L3: 10u; L_Sunlord_MWSA0518_5.4x5.2mm; LCSC Part # C139506
Q1, Q2: AO3401A; SOT-23; LCSC Part # C15127
R1, R2, R8: 100k; R_0603_1608Metric; LCSC Part # C25803
R3: 10k; R_0603_1608Metric; LCSC Part # C25804
R4: 3k3; R_0603_1608Metric; LCSC Part # C22978
R5: 100; R_0603_1608Metric; LCSC Part # C22775
R6, R9: 1M; R_0603_1608Metric; LCSC Part # C22935
R7: 110k; R_0603_1608Metric; LCSC Part # C25805
R10, R11: 12k; R_0603_1608Metric; LCSC Part # C22790
R12: 1k5; R_0603_1608Metric; LCSC Part # C22843
R13: 4k3; R_0603_1608Metric; LCSC Part # C23159
R14: 5k1; R_0603_1608Metric; LCSC Part # C23186
U1: TPS5430DDA; TI_SO-PowerPAD-8_ThermalVias; LCSC Part # C9864
U2: TPS65131RGER; QFN-24-1EP_4x4mm_P0.5mm_EP2.6x2.6mm; Mouser2 Part Number 595-TPS65131RGET

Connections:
+5V: C3.1, C4.1, C5.1, D4.2 (A), J2.1, L1.2, Q2.2 (S), R3.2, R5.2, U2.5 (INN_1), U2.6 (INN_2)
+12V: C9.1, C10.1, D2.1 (K), D5.2 (A), J3.1, R6.2, R10.2, U2.23 (VPOS)
-12V: C11.2, C14.1, D3.2 (A), J4.1, R9.1, R11.2, R14.1, U2.15 (VNEG)
FB: R3.1, R4.2, U1.4 (VSENSE)
GND: C1.2, C3.2, C4.2, C5.2, C6.2, C7.2, C8.2, C10.2, C12.2, C13.2, C14.2, D1.2 (A), D6.2 (A), J1.2, J2.2, J3.2, J4.2, L3.2, Q1.1 (G), R2.1, R4.1, R7.1, R10.1, R11.1, R12.1, R13.1, U1.6 (GND), U1.9 (GNDPAD), U2.2 (PGND_1), U2.3 (PGND_2), U2.19 (AGND), U2.25 (POWERPAD)
unnamed: C1.1, Q1.2 (S), R1.2, U1.7 (VIN)
unnamed: C2.1, U1.1 (BOOT)
unnamed: C2.2, D1.1 (K), L1.1, U1.8 (PH)
unnamed: C6.1, L2.1, Q2.3 (D)
unnamed: C7.1, R5.1, U2.4 (VIN), U2.8 (ENP), U2.9 (PSP), U2.10 (ENN), U2.11 (PSN)
unnamed: C8.1, U2.21 (CP)
unnamed: C9.2, R6.1, R7.2, U2.22 (FBP)
unnamed: C11.1, R8.1, R9.2, U2.16 (FBN)
unnamed: C12.1, R8.2, U2.17 (VREF)
unnamed: C13.1, U2.18 (CN)
unnamed: D2.2 (A), L2.2, U2.1 (INP_1), U2.24 (INP_2)
unnamed: D3.1 (K), L3.1, U2.13 (OUTN_1), U2.14 (OUTN_2)
unnamed: D4.1 (K), R12.2
unnamed: D5.1 (K), R13.2
unnamed: D6.1 (K), R14.2
unnamed: F1.1, Q1.3 (D)
unnamed: Q2.1 (G), U2.7 (BSW)
unnamed: R1.1, R2.2, U1.5 (EN)
VCC: F1.2, J1.1

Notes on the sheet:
VCC to 5V Regulator
5V to +12V / -12V Regulator
Screw Terminals
Indicator LEDs
Mounting Holes
Banana Schplit
Single Rail DC to Split Rail DC Supply
VCC(max) = 12V - Limited by Vgs (Q1)!
V(out) = ((R3 / R4) + 1) * 1.221 = 4.92V
Phoenix 5mm Pitch Screw Terminals
Approx. 2mA per LED
Split Regulator +12V @ 600mA = 7.2W -12V @ 450mA = 5.4W Total = 12.6W
5V Regulator Current to split regulator = 12.6W / 4.92V = 2.56A Remaining current approx 500mA (continuous, peak 1.5A)
Power Calculations

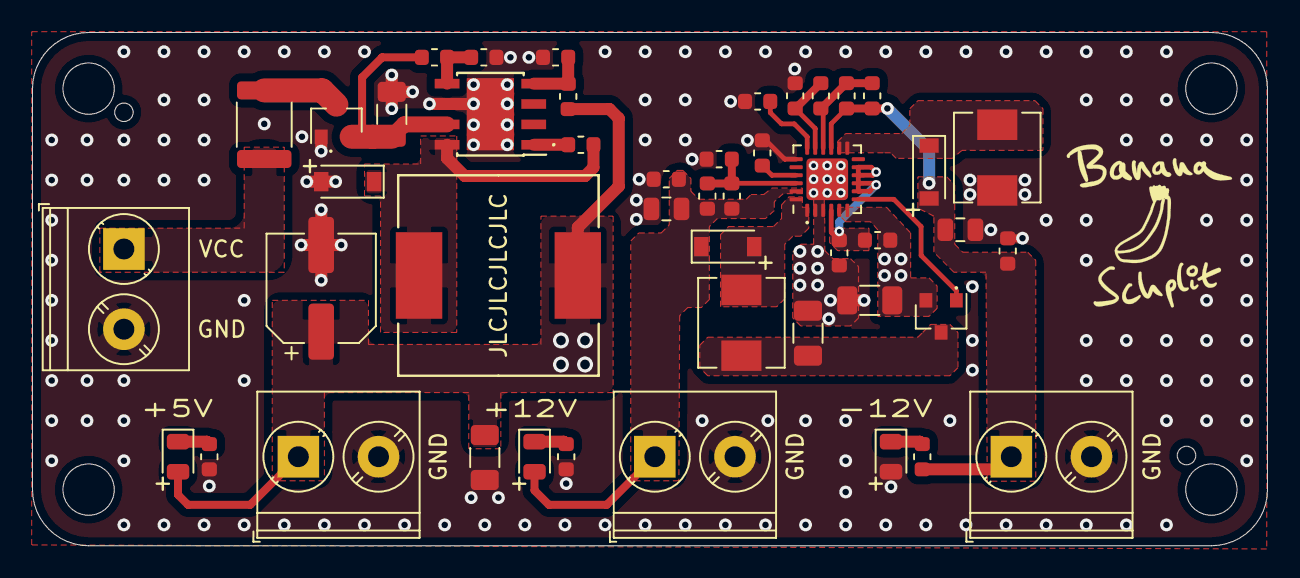
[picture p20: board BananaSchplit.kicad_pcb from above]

Board: 2 copper layers, 77.0 x 32.0 mm, 50 parts (0 on the bottom side), 24 nets.

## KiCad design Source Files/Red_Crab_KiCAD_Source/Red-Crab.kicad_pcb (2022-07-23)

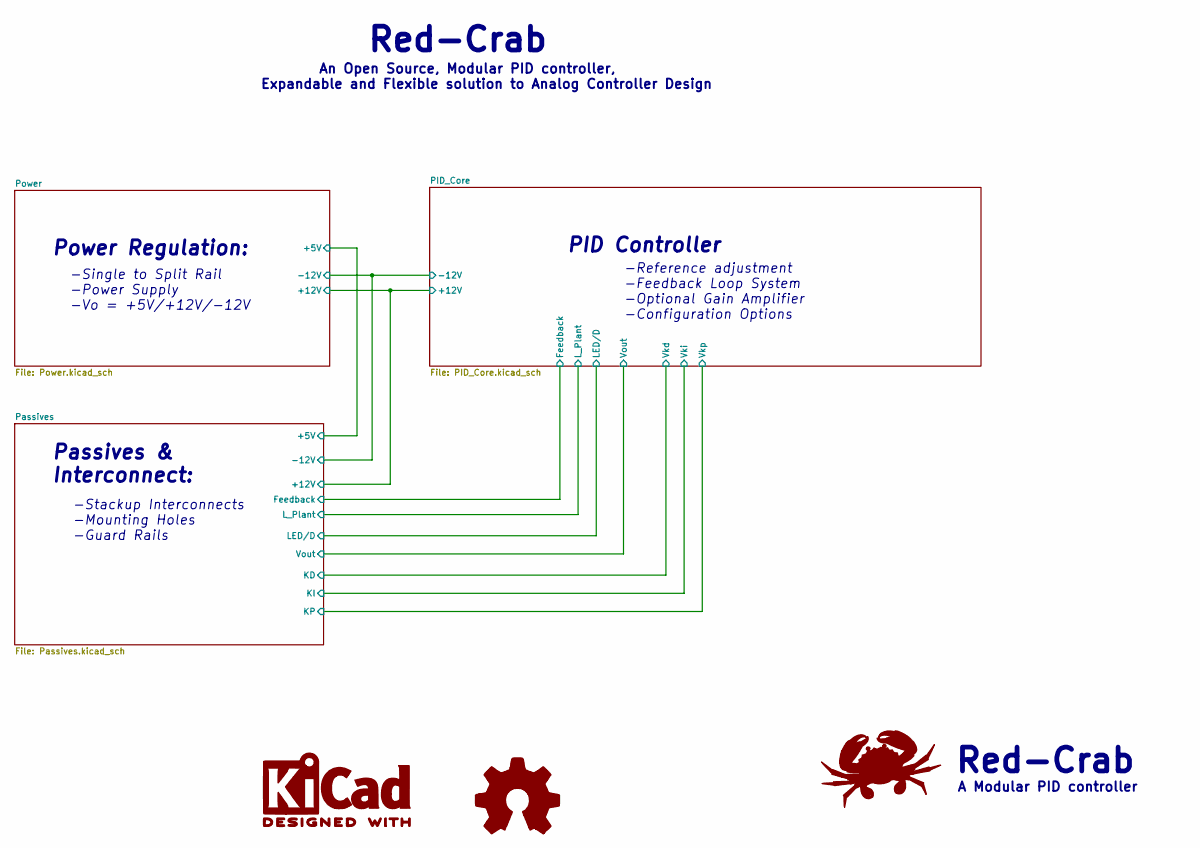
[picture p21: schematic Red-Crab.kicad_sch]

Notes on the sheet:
Passives & Interconnect:
An Open Source, Modular PID controller, Expandable and Flexible solution to Analog Controller Design
Red-Crab
PID Controller
Power Regulation:
-Single to Split Rail -Power Supply -Vo = +5V/+12V/-12V
A Modular PID controller
-Stackup Interconnects -Mounting Holes -Guard Rails
-Reference adjustment -Feedback Loop System -Optional Gain Amplifier -Configuration Options

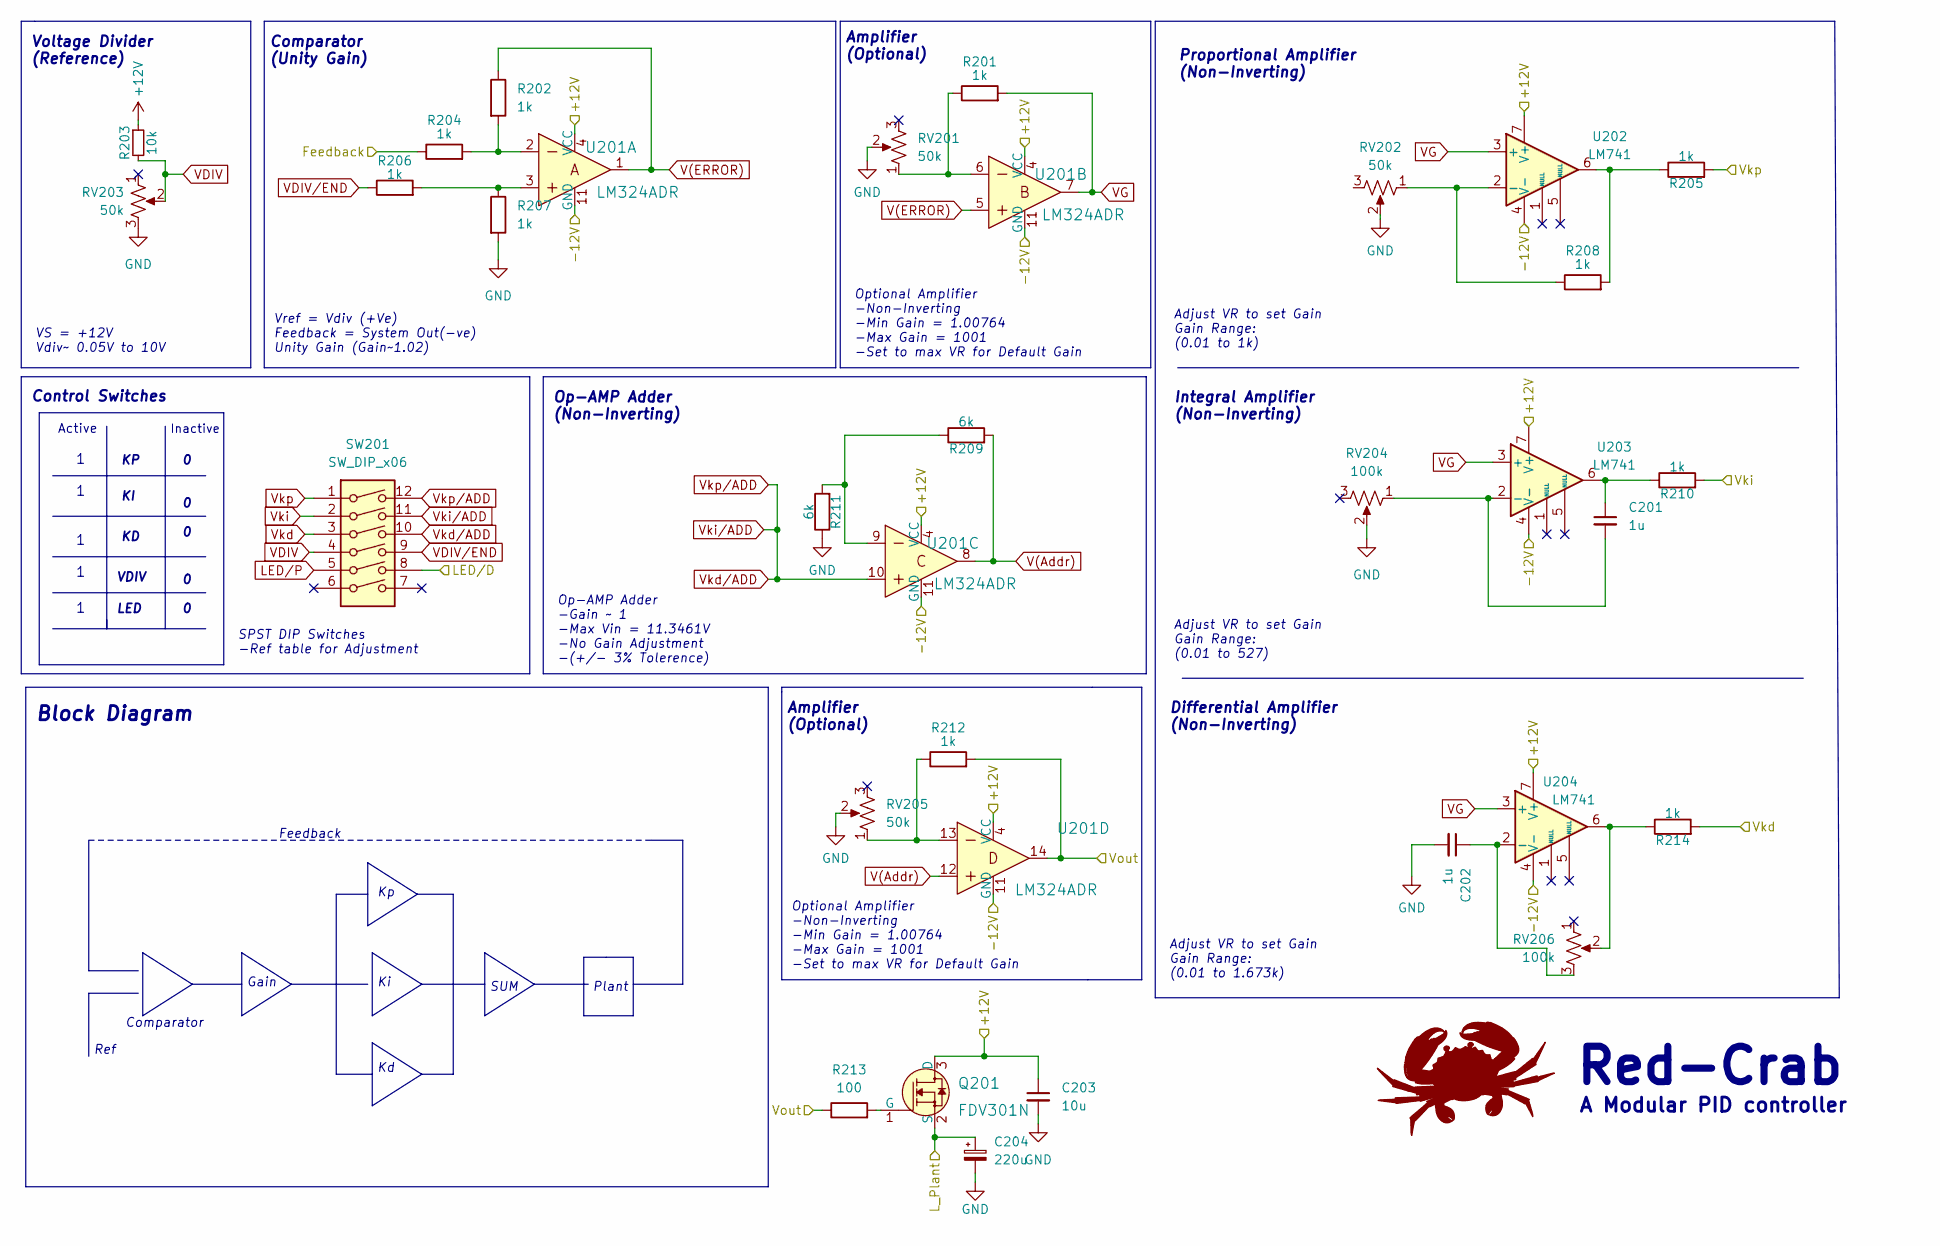
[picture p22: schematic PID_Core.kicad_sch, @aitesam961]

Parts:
C201, C202: 1u; C_1206_3216Metric; LCSC Part # C13585
C203: 10u; C_1206_3216Metric; LCSC Part # C13585
C204: 220u; CP_Elec_6.3x7.7; LCSC Part # C127327
Q201: FDV301N; SOT-23-3; MPN FDV301N; Digi-Key_PN FDV301NCT-ND
R201, R202, R204, R205, R206, R207, R208, R210, R212, R214: 1k; R_0402_1005Metric
R203: 10k; R_0603_1608Metric; LCSC Part # C22775
R209, R211: 6k; R_0402_1005Metric
R213: 100; R_0402_1005Metric
RV201, RV202, RV203, RV205: 50k; Potentiometer_Bourns_3214X_Vertical
RV204, RV206: 100k; Potentiometer_Bourns_3214X_Vertical
SW201: SW_DIP_x06; SW_DIP_SPSTx08_Slide_6.7x21.88mm_W8.61mm_P2.54mm_LowProfile
U201: LM324ADR; SOIC-14_W3.9mm; MPN LM324ADR; Digi-Key_PN 296-9540-1-ND
U202, U203, U204: LM741; SOP-8_3.76x4.96mm_P1.27mm

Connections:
+12V: C203.1, Q201.3 (D), R203.1, U201.4 (VCC), U202.7 (V+), U203.7 (V+), U204.7 (V+); also elsewhere on the board
-12V: U201.11 (GND), U202.4 (V-), U203.4 (V-), U204.4 (V-); also elsewhere on the board
/PID_Core/Feedback: R204.1; also elsewhere on the board
/PID_Core/LED/D: SW201.8; also elsewhere on the board
/PID_Core/L_Plant: C204.1, Q201.2 (S); also elsewhere on the board
/PID_Core/Vout: R212.2, R213.1, U201.14; also elsewhere on the board
GND: C202.2, C203.2, C204.2, R207.2, R211.1, RV201.2, RV202.2, RV203.3, RV204.2, RV205.2; also elsewhere on the board
LED/P: SW201.5
unnamed: C201.1, R210.1, U203.6
unnamed: C201.2, RV204.1, U203.2 (-)
unnamed: C202.1, RV206.3, U204.2 (-)
unnamed: Q201.1 (G), R213.2
unnamed: R201.1, RV201.1, U201.6
unnamed: R202.2, R204.2, U201.2
unnamed: R205.1, R208.2, U202.6
unnamed: R206.2, R207.1, U201.3
unnamed: R208.1, RV202.1, U202.2 (-)
unnamed: R209.1, R211.2, U201.9
unnamed: R212.1, RV205.1, U201.13
unnamed: R214.1, RV206.2, U204.6
V(Addr): R209.2, U201.8, U201.12
V(ERROR): R202.1, U201.1, U201.5
VDIV: R203.2, RV203.2, SW201.4
VDIV/END: R206.1, SW201.9
VG: R201.2, U201.7, U202.3 (+), U203.3 (+), U204.3 (+)
Vkd: R214.2, SW201.3; also elsewhere on the board
Vkd/ADD: SW201.10, SW201.11, SW201.12, U201.10
Vki: R210.2, SW201.2; also elsewhere on the board
Vkp: R205.2, SW201.1; also elsewhere on the board

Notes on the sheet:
Comparator (Unity Gain)
VDIV
Amplifier (Optional)
SUM
VS = +12V Vdiv~ 0.05V to 10V
Proportional Amplifier (Non-Inverting)
Optional Amplifier -Non-Inverting -Min Gain = 1.00764 -Max Gain = 1001 -Set to max VR for Default Gain
Op-AMP Adder (Non-Inverting)
Inactive
Block Diagram
Red-Crab
0 0
1 1
Ref
Integral Amplifier (Non-Inverting)
Op-AMP Adder -Gain ~ 1 -Max Vin = 11.3461V -No Gain Adjustment -(+/- 3% Tolerence)
Plant
Feedback
Adjust VR to set Gain Gain Range: (0.01 to 1.673k)
Voltage Divider (Reference)
Adjust VR to set Gain Gain Range: (0.01 to 527)
Control Switches
Vref = Vdiv (+Ve) Feedback = System Out(-ve) Unity Gain (Gain~1.02)
Gain
SPST DIP Switches -Ref table for Adjustment
LED
Active
Differential Amplifier (Non-Inverting)
A Modular PID controller
Adjust VR to set Gain Gain Range: (0.01 to 1k)
Comparator

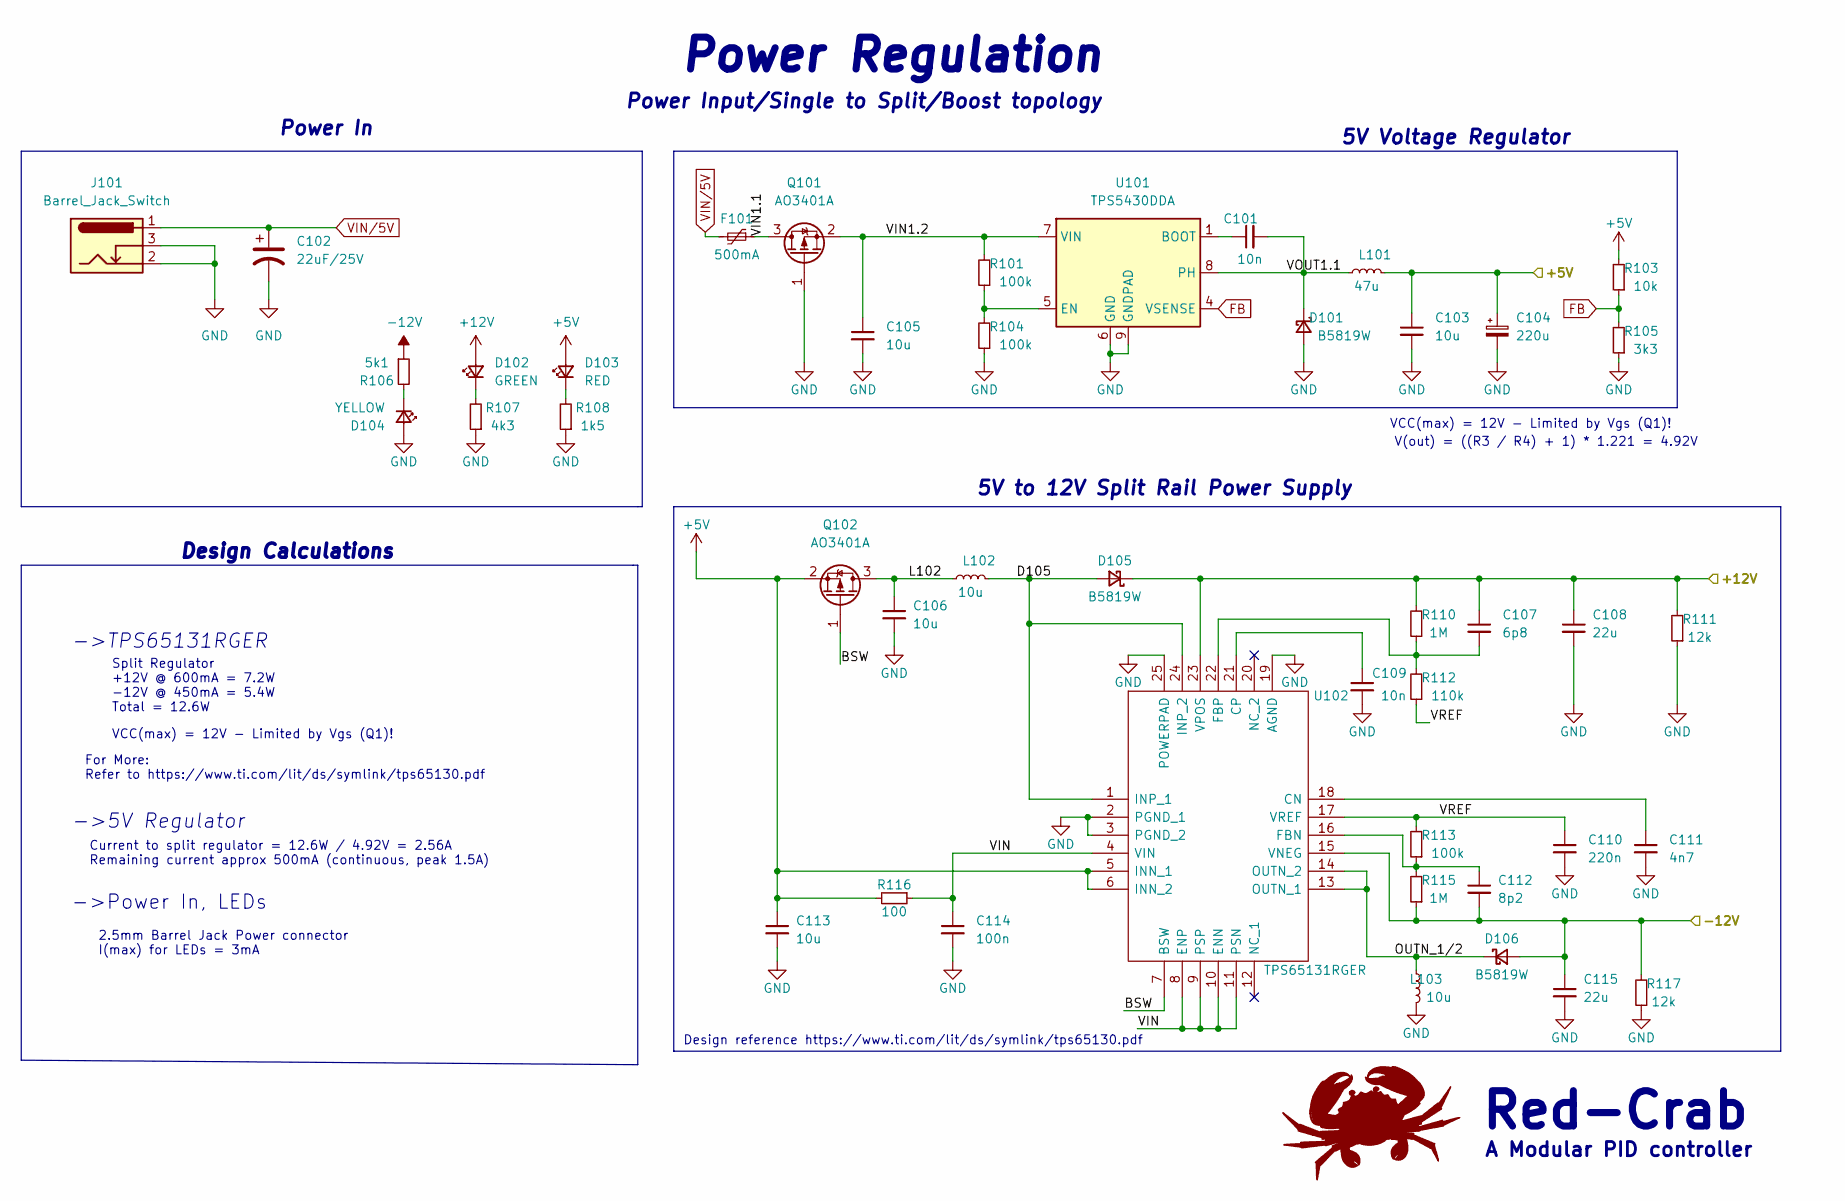
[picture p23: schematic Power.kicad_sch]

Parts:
C101, C109: 10n; C_0603_1608Metric; LCSC Part # C57112
C102: 22uF/25V; CP_Elec_6.3x5.3
C103, C105, C106, C113: 10u; C_1206_3216Metric; LCSC Part # C13585
C104: 220u; CP_Elec_6.3x7.7; LCSC Part # C127327
C107: 6p8; C_0603_1608Metric; LCSC Part # C1679
C108, C115: 22u; C_0805_2012Metric; LCSC Part # C45783
C110: 220n; C_0603_1608Metric; LCSC Part # C21120
C111: 4n7; C_0603_1608Metric; LCSC Part # C53987
C112: 8p2; C_0603_1608Metric; LCSC Part # C1685
C114: 100n; C_0603_1608Metric; LCSC Part # C14663
D101, D105, D106: B5819W; D_SOD-123; LCSC Part # C8598
D102: GREEN; LED_0805_2012Metric; LCSC Part # C2297
D103: RED; LED_0805_2012Metric; LCSC Part # C84256
D104: YELLOW; LED_0805_2012Metric; LCSC Part # C2296
F101: 500mA; Fuse_1812_4532Metric; LCSC Part # C151168
J101: Barrel_Jack_Switch; BarrelJack_GCT_DCJ200-10-A_Horizontal
L101: 47u; L_Sunlord_MWSA0518_5.4x5.2mm; LCSC Part # C169398
L102, L103: 10u; L_Sunlord_MWSA0518_5.4x5.2mm; LCSC Part # C139506
Q101, Q102: AO3401A; SOT-23; LCSC Part # C15127
R101, R104, R113: 100k; R_0603_1608Metric; LCSC Part # C25803
R103: 10k; R_0603_1608Metric; LCSC Part # C25804
R105: 3k3; R_0603_1608Metric; LCSC Part # C22978
R106: 5k1; R_0603_1608Metric; LCSC Part # C23186
R107: 4k3; R_0603_1608Metric; LCSC Part # C23159
R108: 1k5; R_0603_1608Metric; LCSC Part # C22843
R110, R115: 1M; R_0603_1608Metric; LCSC Part # C22935
R111, R117: 12k; R_0603_1608Metric; LCSC Part # C22790
R112: 110k; R_0603_1608Metric; LCSC Part # C25805
R116: 100; R_0603_1608Metric; LCSC Part # C22775
U101: TPS5430DDA; TI_SO-PowerPAD-8_ThermalVias; LCSC Part # C9864
U102: TPS65131RGER; QFN-24-1EP_4x4mm_P0.5mm_EP2.6x2.6mm; Mouser2 Part Number 595-TPS65131RGET

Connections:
+5V: C103.1, C104.1, C113.1, D103.2 (A), L101.2, Q102.2 (S), R103.2, R116.2, U102.5 (INN_1), U102.6 (INN_2); also elsewhere on the board
+12V: C107.1, C108.1, D102.2 (A), D105.1 (K), R110.2, R111.2, U102.23 (VPOS); also elsewhere on the board
-12V: C112.2, C115.1, D106.2 (A), R106.1, R115.1, R117.2, U102.15 (VNEG); also elsewhere on the board
/Power/BSW: Q102.1 (G), U102.7 (BSW)
/Power/D105: D105.2 (A), L102.2, U102.1 (INP_1), U102.24 (INP_2)
/Power/L102: C106.1, L102.1, Q102.3 (D)
/Power/OUTN_1/2: D106.1 (K), L103.1, U102.13 (OUTN_1), U102.14 (OUTN_2)
/Power/VIN: C114.1, R116.1, U102.4 (VIN), U102.8 (ENP), U102.9 (PSP), U102.10 (ENN), U102.11 (PSN)
/Power/VIN1.1: F101.1, Q101.3 (D)
/Power/VIN1.2: C105.1, Q101.2 (S), R101.2, U101.7 (VIN)
/Power/VOUT1.1: C101.2, D101.1 (K), L101.1, U101.8 (PH)
/Power/VREF: C110.1, R112.1, R113.2, U102.17 (VREF)
FB: R103.1, R105.2, U101.4 (VSENSE)
GND: C102.2, C103.2, C104.2, C105.2, C106.2, C108.2, C109.2, C110.2, C111.2, C113.2, C114.2, C115.2, D101.2 (A), D104.2 (A), J101.2, J101.3, L103.2, Q101.1 (G), R104.1, R105.1, R107.1, R108.1, R111.1, R117.1, U101.6 (GND), U101.9 (GNDPAD), U102.2 (PGND_1), U102.3 (PGND_2), U102.19 (AGND), U102.25 (POWERPAD); also elsewhere on the board
unnamed: C101.1, U101.1 (BOOT)
unnamed: C107.2, R110.1, R112.2, U102.22 (FBP)
unnamed: C109.1, U102.21 (CP)
unnamed: C111.1, U102.18 (CN)
unnamed: C112.1, R113.1, R115.2, U102.16 (FBN)
unnamed: D102.1 (K), R107.2
unnamed: D103.1 (K), R108.2
unnamed: D104.1 (K), R106.2
unnamed: R101.1, R104.2, U101.5 (EN)
VIN/5V: C102.1, F101.2, J101.1

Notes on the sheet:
Design reference https://www.ti.com/lit/ds/symlink/tps65130.pdf
Split Regulator +12V @ 600mA = 7.2W -12V @ 450mA = 5.4W Total = 12.6W
Design Calculations
->5V Regulator
A Modular PID controller
Power Input/Single to Split/Boost topology
V(out) = ((R3 / R4) + 1) * 1.221 = 4.92V
5V Voltage Regulator
5V to 12V Split Rail Power Supply
->TPS65131RGER
VCC(max) = 12V - Limited by Vgs (Q1)!
Red-Crab
Current to split regulator = 12.6W / 4.92V = 2.56A Remaining current approx 500mA (continuous, peak 1.5A)
->Power In, LEDs
Power In
For More: Refer to https://www.ti.com/lit/ds/symlink/tps65130.pdf
Power Regulation
2.5mm Barrel Jack Power connector I(max) for LEDs = 3mA

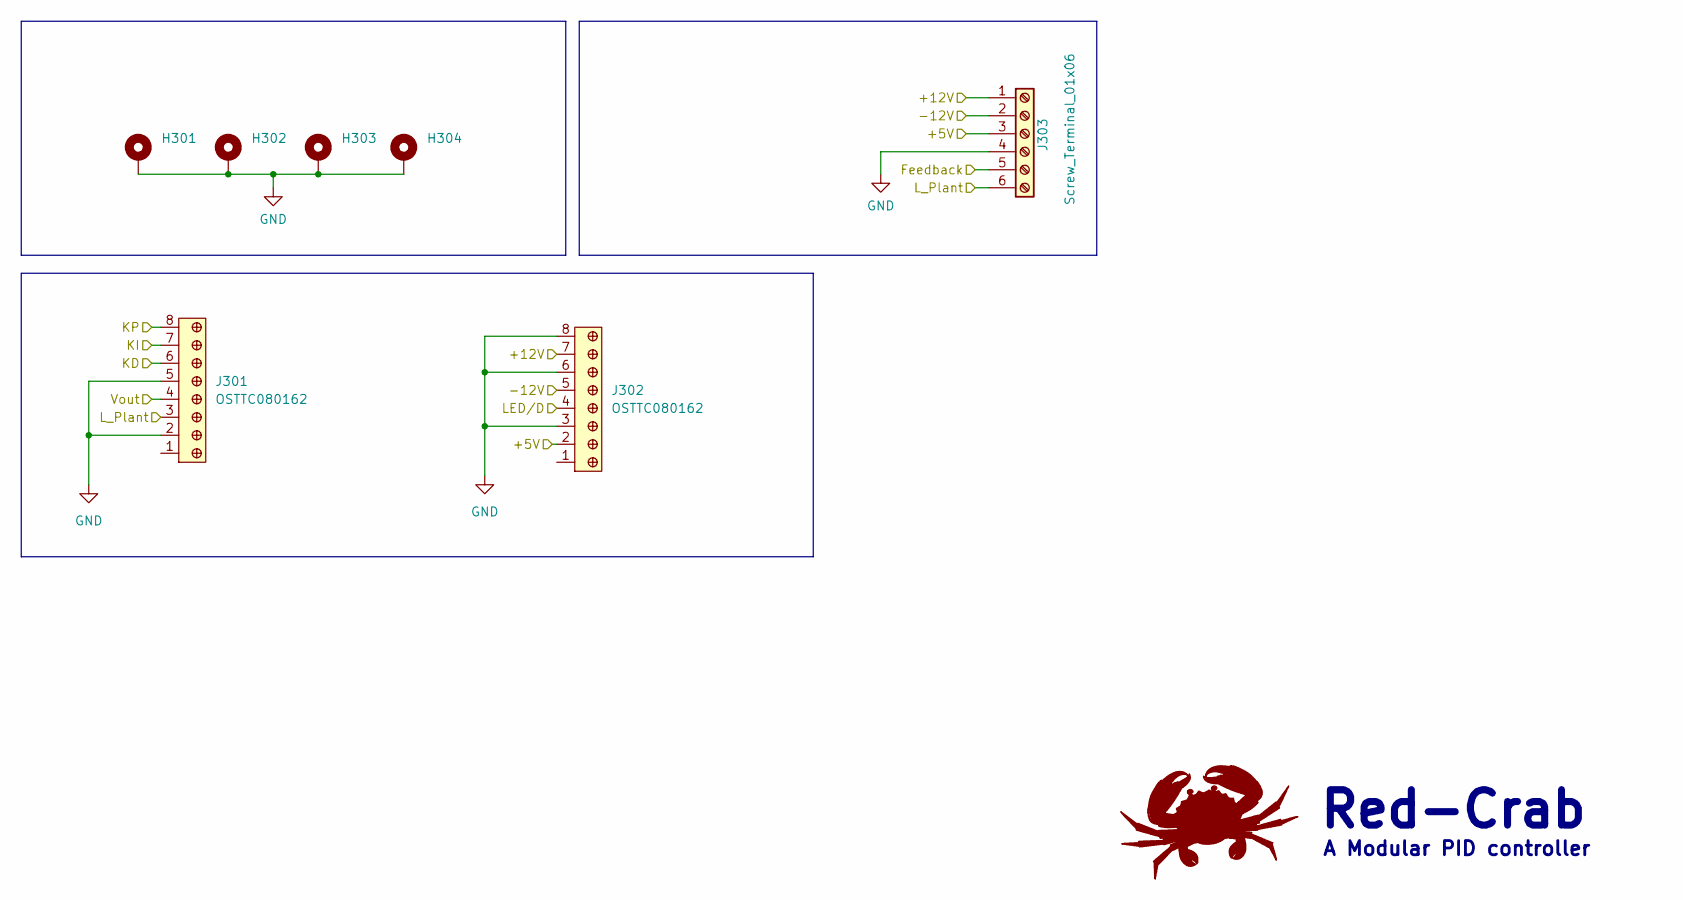
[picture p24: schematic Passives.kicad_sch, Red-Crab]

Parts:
H301, H302, H303, H304: MountingHole_Pad; MountingHole_2.2mm_M2_Pad_Via
J301, J302: OSTTC080162; PinHeader_1x08_P1.27mm_Vertical_SMD_Pin1Left; MPN OSTTC080162; Digi-Key_PN ED2606-ND
J303: Screw_Terminal_01x06; Stocko_MKS_1656-6-0-606_1x6_P2.50mm_Vertical

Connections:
+5V: J302.2, J303.3; also elsewhere on the board
+12V: J302.7, J303.1; also elsewhere on the board
-12V: J302.5, J303.2; also elsewhere on the board
/PID_Core/Feedback: J303.5; also elsewhere on the board
/PID_Core/LED/D: J302.4; also elsewhere on the board
/PID_Core/L_Plant: J301.3, J303.6; also elsewhere on the board
/PID_Core/Vout: J301.4; also elsewhere on the board
GND: H301.1, H302.1, H303.1, H304.1, J301.2, J301.5, J302.3, J302.6, J302.8, J303.4; also elsewhere on the board
Vkd: J301.6; also elsewhere on the board
Vki: J301.7; also elsewhere on the board
Vkp: J301.8; also elsewhere on the board

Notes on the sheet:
Red-Crab
A Modular PID controller

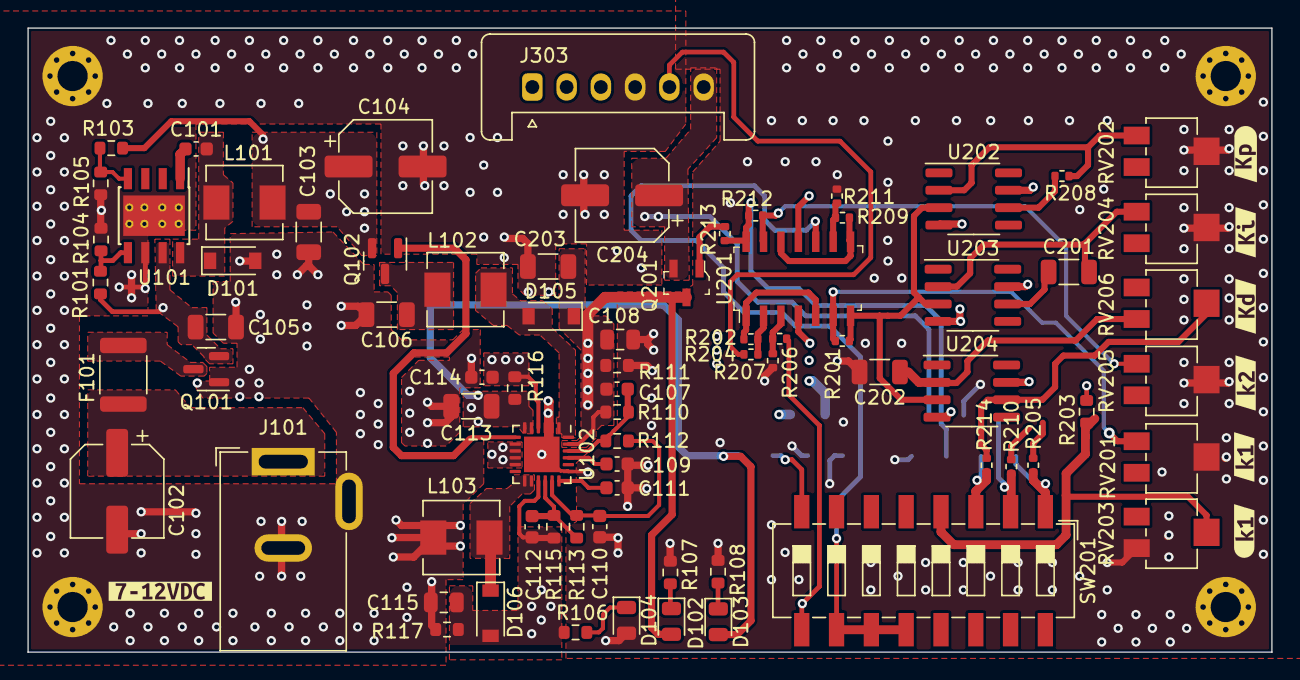
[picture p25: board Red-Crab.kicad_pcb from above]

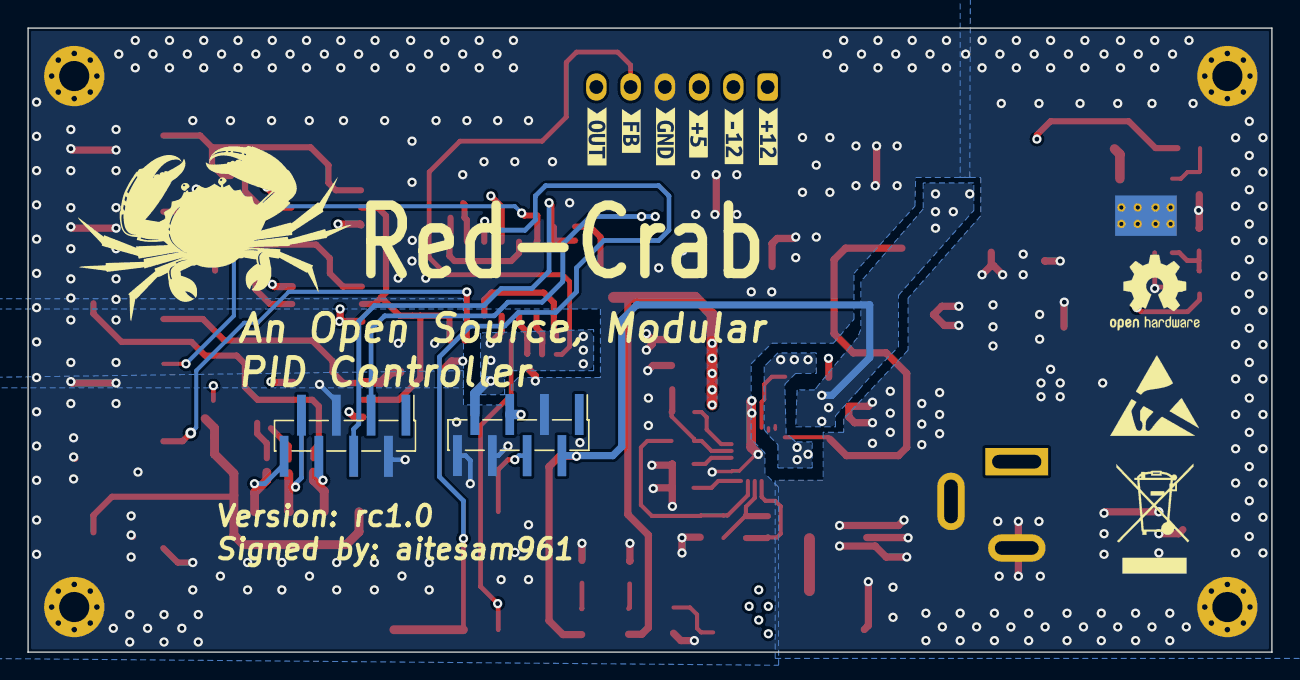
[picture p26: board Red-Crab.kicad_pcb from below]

Board: 4 copper layers, 90.8 x 45.5 mm, 94 parts (8 on the bottom side), 49 nets.

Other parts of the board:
kibuzzard-62D28A8A: G***; kibuzzard-62D28A8A
kibuzzard-62D28A66: G***; kibuzzard-62D28A66
kibuzzard-62D28AAB: G***; kibuzzard-62D28AAB
kibuzzard-62D28AD0: G***; kibuzzard-62D28AD0
kibuzzard-62D28B16: G***; kibuzzard-62D28B16
kibuzzard-62D28BAA: G***; kibuzzard-62D28BAA
kibuzzard-62D28C0C: G***; kibuzzard-62D28C0C
kibuzzard-62D562E5: G***; kibuzzard-62D562E5
kibuzzard-62D5635A: G***; kibuzzard-62D5635A
kibuzzard-62D5638B: G***; kibuzzard-62D5638B
kibuzzard-62D56315: G***; kibuzzard-62D56315
kibuzzard-62D56342: G***; kibuzzard-62D56342
kibuzzard-62D56368: G***; kibuzzard-62D56368
